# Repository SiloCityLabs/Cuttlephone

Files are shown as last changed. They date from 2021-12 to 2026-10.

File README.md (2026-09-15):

# Cuttlephone
Cuttlephone is phone case generator and gamepad system for 3D printing. This is the source code. [Get premade 3D models and print tutorials on the website](https://cuttlephone.com/)

phone case generator

3D printed phone case, in a 3D printed adapter for Razer Junglecat controllers

# Features
 - hard plastic (PLA+, ABS, PETG) or flexible (TPU)
 - phone case mode
 - universal phone clamp mode
 - Switch Joy-Con rails
 - Razer Junglecat rails
 
 # How to use phone case generator
 - install [OpenSCAD](https://openscad.org/downloads.html) version 2021.01 or greater
 - Download the code and its dependencies using the git command line: `git clone https://github.com/SiloCityLabs/Cuttlephone.git --recurse-submodules`
 - open the file "phone_case.scad" to use the GUI
 
 # Build scripts
 - in bash run `sh build.sh` to create all variants for all phones
 - GitHub Actions uploads those files to a [GitHub Release](https://github.com/SiloCityLabs/Cuttlephone/releases)

# How to run the docs blog locally

### With Docker:
 - `cd docs`
 - `docker compose up --build`
 - open http://127.0.0.1:4000/

### With Ruby on the host:
 - install Ruby 3.3 or newer, gem, and bundle
 - `cd docs`
 - `bundle install`
 - `sh run.sh`
 - watch the console for something like this: `Server address: http://127.0.0.1:4000/`

A GitHub token is optional. `jekyll-remote-theme` downloads the theme through the GitHub API, which is rate limited to 60 requests an hour without one. If you hit that limit:
- generate a token at https://github.com/settings/tokens/new with the scope *public_repo*
- copy `docs/.env.example` to `docs/.env`
- add token to `docs/.env`

# Build logs 

You can follow progress here:
 - [HackADay.io project log](https://hackaday.io/project/165606-cuttlephone-gamepad-phone-case)
 - [SiloCityLabs project blog / newsletter](https://silocitylabs.com/categories/projects/)
 - [SiloCityLabs Twitter](https://twitter.com/silocitylabs)

# Roadmap

...

Licensed under Creative Commons CC-BY-SA 4.0

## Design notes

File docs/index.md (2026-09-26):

---
title: Cuttlephone
nav_order: 1
---

# Cuttlephone: 3D printable phone cases 

Cuttlephone is the shape-shifting phone case. Download pre-made models or create your own with the OpenSCAD customizer.

## Features

### Hard plastic (PLA+, ABS) or flexibles (TPU)

Print rigid shells from common filament like PLA+ and PETG. Print flexible shells with integrated buttons using TPU.

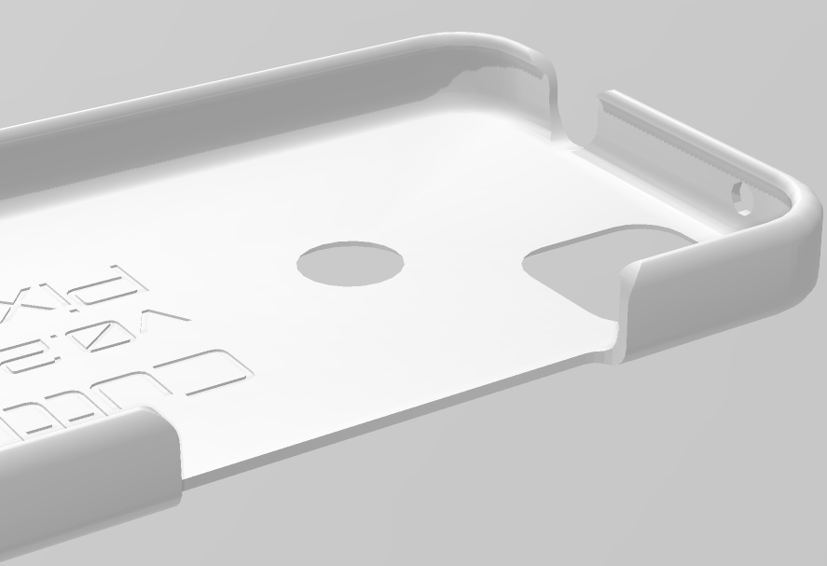
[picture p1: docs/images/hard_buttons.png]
Hard case with cut-out button holes
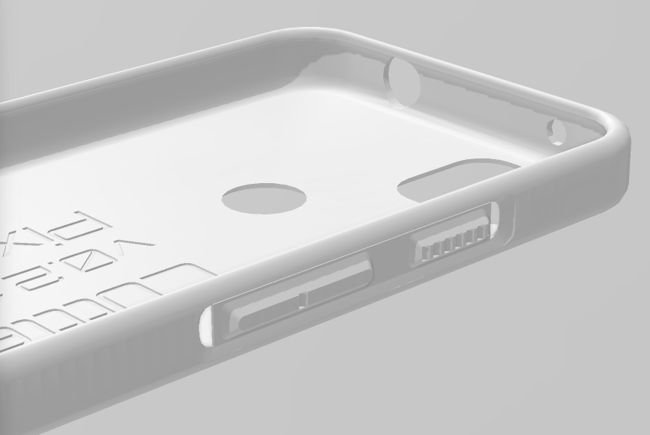
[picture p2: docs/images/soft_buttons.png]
Soft TPU phone case showing flexible push-through side buttons
  |  

### Phone case

Protective 3D printable phone cases sized for specific devices, with cutouts for camera, buttons, and ports, all tuned in the generator.

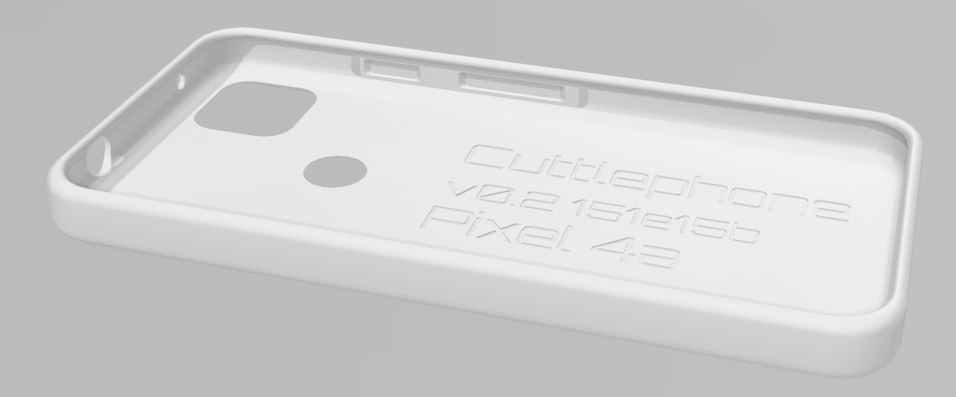
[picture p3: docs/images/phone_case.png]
3D render of a Cuttlephone protective phone case shell


### Switch Joy-Con rails

Slide-on rails for Switch Joy-Con controllers. Yes the locking notch and release button work!

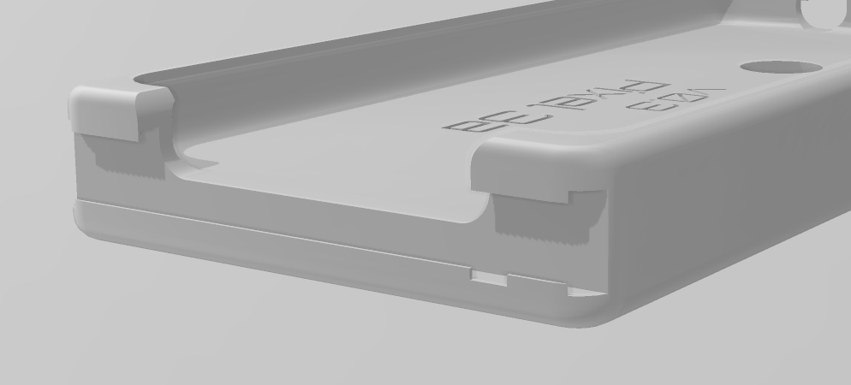
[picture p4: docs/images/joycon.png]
Phone case with Nintendo Switch Joy-Con slide rails on both sides


### Razer Junglecat rails

Slide-on rails for Razer Junglecat controllers.

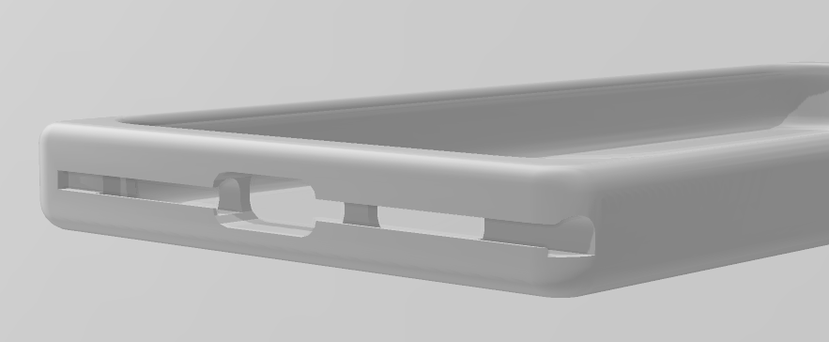
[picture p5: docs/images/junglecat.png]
Phone case with Razer Junglecat controller rails on both sides


### Universal controller adapter

A clamp-style adapter with rails for game controllers. Use one adapter across multiple devices.

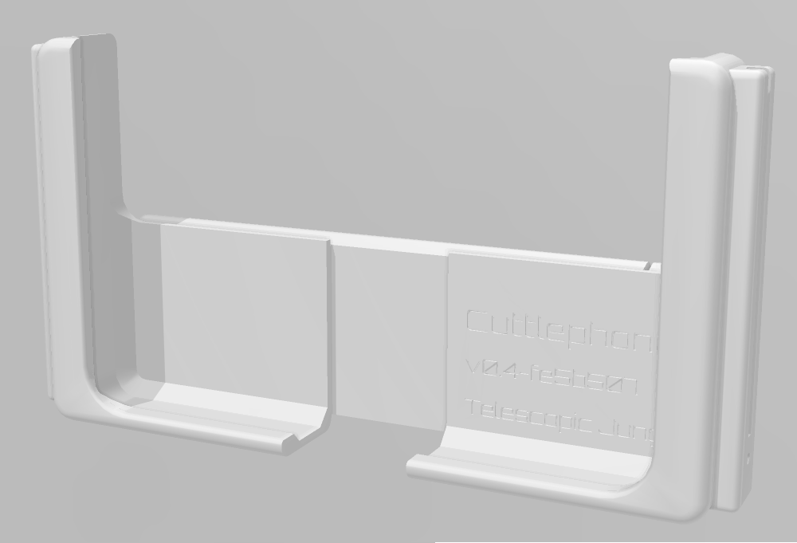
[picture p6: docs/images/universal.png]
Universal clamp phone adapter with controller rails


You can follow progress here:
 - [HackADay.io project log](https://hackaday.io/project/165606-cuttlephone-gamepad-phone-case)
 - [SiloCityLabs project blog / newsletter](https://silocitylabs.com/categories/projects/)
 - [SiloCityLabs Twitter](https://twitter.com/silocitylabs)

Licensed under Creative Commons CC-BY-SA 4.0

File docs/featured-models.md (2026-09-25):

---
layout: default
title: "Featured Models"
description: "User-tested Cuttlephone downloads: Pixel 4a Junglecat case, Joy-Con and Junglecat adapters, and Junglecat rail cutting tool."
permalink: /models/featured-models/
parent: 3D Models
nav_order: 1
---

# Featured Models

The best 3D models, tested by users. These models have been printed and used daily.

## Pixel 4a, with Junglecat rails

Cuttlephone version: v0.5

My daily phone case with Junglecat rails and our first mascot. Print with TPU. Use the [rail cutting tool](#junglecat-rail-cutting-tool) below to remove the support material.

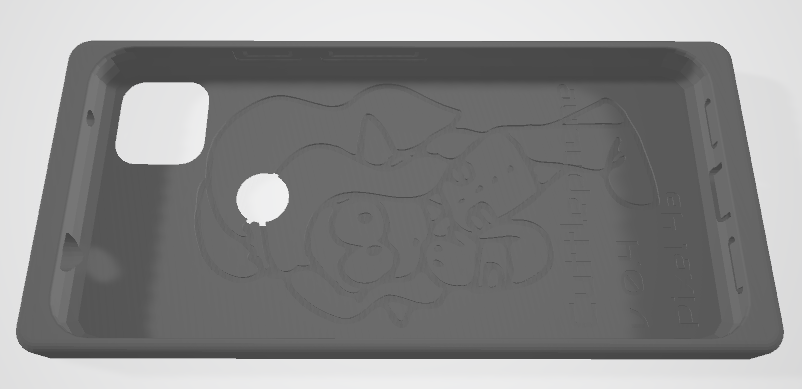
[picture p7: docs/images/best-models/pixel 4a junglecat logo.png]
Pixel 4a phone case with Junglecat rails (https://github.com/SiloCityLabs/Cuttlephone/releases/download/v0.5/Pixel_4a_junglecat_soft.3mf)


[3MF file](https://github.com/SiloCityLabs/Cuttlephone/releases/download/v0.5/Pixel_4a_junglecat_soft.3mf)

## Nintendo Switch Joy-Con controller adapters

Cuttlephone version: v0.5

Universal phone adapter with Joy-Con rails. Use a rubber band to clamp the two parts together. Comes in horizontal and vertical configurations. This model includes manual supports for the Joy-Con's rail locking notch, but you still need to support the other hanging parts. See the print guide.

[Horizontal:](https://github.com/SiloCityLabs/Cuttlephone/releases/download/v0.5/Telescopic_Joycon_joycon_hard.3mf)

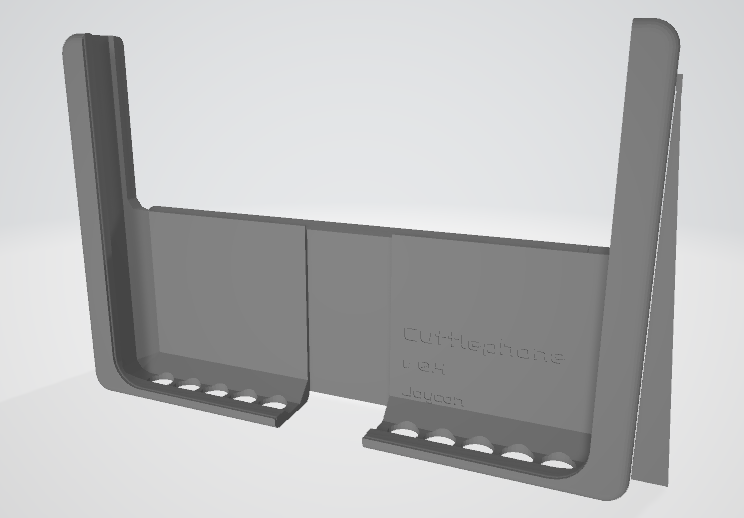
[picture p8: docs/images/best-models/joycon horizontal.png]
Joy-Con horizontal phone adapter (https://github.com/SiloCityLabs/Cuttlephone/releases/download/v0.5/Telescopic_Joycon_joycon_hard.3mf)


[Vertical:](https://github.com/SiloCityLabs/Cuttlephone/releases/download/v0.5/Telescopic_Joycon_Vertical_joycon_hard.3mf)

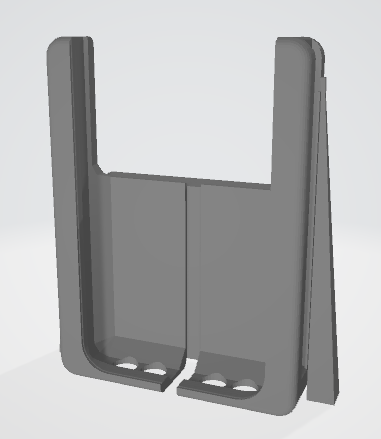
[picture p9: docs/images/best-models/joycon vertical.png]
Joy-Con vertical phone adapter (https://github.com/SiloCityLabs/Cuttlephone/releases/download/v0.5/Telescopic_Joycon_Vertical_joycon_hard.3mf)


## Razer Junglecat controller adapters

Universal phone adapter with Junglecat rails. Use a rubber band to clamp the two parts together.

[Horizontal:](https://github.com/SiloCityLabs/Cuttlephone/releases/download/v0.5/Telescopic_Junglecat_junglecat_hard.3mf)

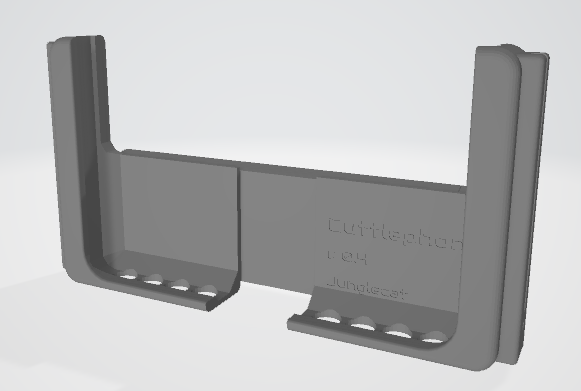
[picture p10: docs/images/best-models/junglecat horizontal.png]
Junglecat horizontal phone adapter (https://github.com/SiloCityLabs/Cuttlephone/releases/download/v0.5/Telescopic_Junglecat_junglecat_hard.3mf)


[Vertical:](https://github.com/SiloCityLabs/Cuttlephone/releases/download/v0.5/Telescopic_Junglecat_Vertical_junglecat_hard.3mf)

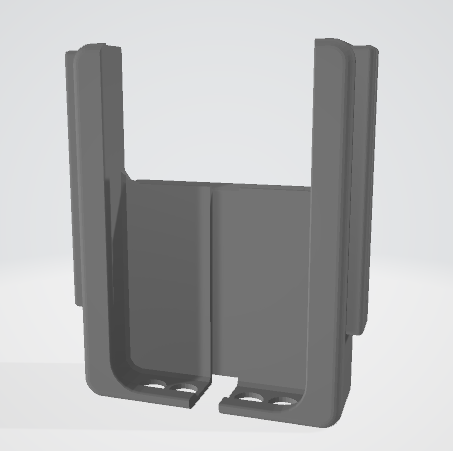
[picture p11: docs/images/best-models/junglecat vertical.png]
Junglecat vertical phone adapter (https://github.com/SiloCityLabs/Cuttlephone/releases/download/v0.5/Telescopic_Junglecat_Vertical_junglecat_hard.3mf)


## Junglecat rail cutting tool

A tool to help cut the support material from the Junglecat rails. For phone cases, printed flat, with the manual supports.

[Rail cut tool:](https://github.com/SiloCityLabs/Cuttlephone/releases/download/v0.5/Junglecat_rail_cut_tool.3mf)

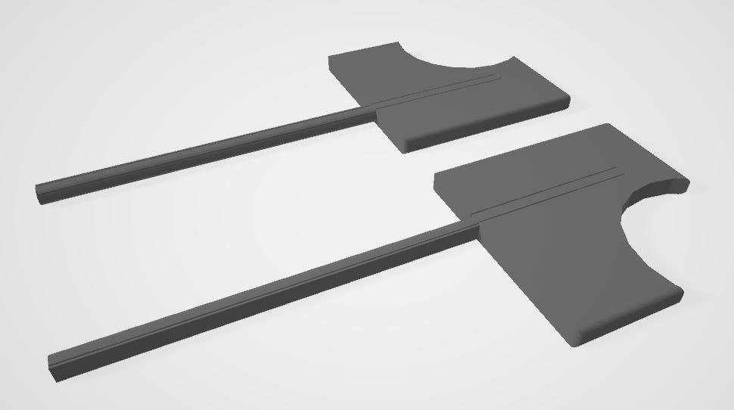
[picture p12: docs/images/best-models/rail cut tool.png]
Rail cutting tool (https://github.com/SiloCityLabs/Cuttlephone/releases/download/v0.5/Junglecat_rail_cut_tool.3mf)


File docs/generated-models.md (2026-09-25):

---
layout: default
title: "Generated Models"
description: "Download every Cuttlephone phone case variant in hard or soft materials, with optional Joy-Con or Junglecat rails."
permalink: /models/generated-models/
parent: 3D Models
nav_order: 2
---

# Generated models
Below you'll find models of every available phone case with every available variation. I generate a new batch with each significant revision of the program. 

Models are from the [latest release]({{ site.github.repository_url }}/releases/latest).

{% for material in site.data.case_materials %} For {{ material.material }} cases, print with {{material.example}}. {% endfor %} Read the [3D printing guide](/guides/print-guide/) for more tips.

<style>
  a.model-link {
    display: inline-block;
    margin: 0.2em 0.4em 0.2em 0;
  }
</style>

<!-- loop through phone_case.json -->
{% for model in site.data.phone_case.parameterSets %}
{% if model[1].in_development != "true" %}
<!-- hide models that don't have build output -->
{% assign any_built = "" %}
{% for type in site.data.model_types %}
{% if type.build_key %}
{% assign build_flag = model[1][type.build_key] %}
{% if build_flag == "true" %}{% assign any_built = "yes" %}{% endif %}
{% endif %}
{% endfor %}
{% if any_built == "yes" %}
## {{ model[0] }}

<table>
<thead>
<tr>
<th>Type</th>
{% for material in site.data.case_materials %}
{% assign mat_built = "" %}
{% if material.material == "hard" and model[1].build_hard == "true" %}{% assign mat_built = "yes" %}{% endif %}
{% if material.material == "soft" and model[1].build_soft == "true" %}{% assign mat_built = "yes" %}{% endif %}
<!-- muted text if no build output -->
<th{% unless mat_built == "yes" %} style="opacity:0.45;font-weight:500"{% endunless %}>{{ material.material | capitalize }}</th>
{% endfor %}
</tr>
</thead>
<tbody>
{% for type in site.data.model_types %}
{% if type.build_key %}
{% assign build_flag = model[1][type.build_key] %}
{% if build_flag == "true" %}
{% include_relative premade-models-link.md %}
{% endif %}
{% endif %}
{% endfor %}
</tbody>
</table>
{% endif %}
{% endif %}
{% endfor %}

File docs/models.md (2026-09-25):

---
layout: default
title: "3D Models"
description: "Download featured and generated Cuttlephone 3D printable phone cases, Joy-Con adapters, and Junglecat adapters. Preview pre-built models in the browser."
permalink: /models/
has_children: true
has_toc: false
heading_anchors: false
---

# 3D Models

## [Featured Models](/models/featured-models/)

The best phone cases and controller adapters, as tested by users.

## [Generated models](/models/generated-models/)

All 3D models - all phone models with each variation of material and controller

## [3D Preview](/models/preview/)

Rotate and zoom a release model in the browser

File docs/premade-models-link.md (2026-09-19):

<tr>
<td>{{ type.model_type }}</td>
{%- for material in site.data.case_materials -%}
<td>
<!-- loop through materials -->
<!-- Liquid has no real booleans; assign false becomes the truthy string "false" -->
{%- assign can_build = "" -%}
{%- if material.material == "hard" and model[1].build_hard == "true" -%}{%- assign can_build = "yes" -%}{%- endif -%}
{%- if material.material == "soft" and model[1].build_soft == "true" -%}{%- assign can_build = "yes" -%}{%- endif -%}
{%- if can_build == "yes" -%}
{%- capture filename %}{{ model[0] }} {{ type.model_type }} {{ material.material }}.3mf{% endcapture -%}
<!-- github-safe file names -->
{%- assign filename = filename | strip | replace: " ", "_" | replace: "+", "plus" -%}
<a class="model-link" href="{{ site.release_download_url }}{{ filename }}">Download 3MF</a>
<br>
<a class="model-link" href="{{ '/models/preview/' | relative_url }}?model={{ filename | url_encode }}{% if model[1].rotate_upright == "true" %}&rotate_upright=true{% endif %}">Preview</a>
{%- endif -%}
</td>
{%- endfor -%}
</tr>

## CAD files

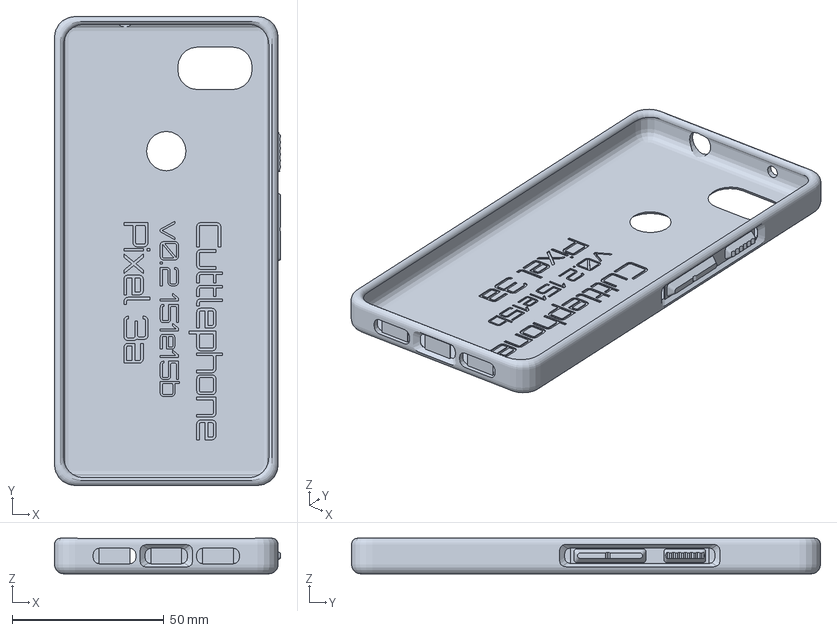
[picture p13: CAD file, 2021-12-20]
docs/premade_models/Pixel 3a phone case soft.3mf
74.6 x 154.7 x 11.8 mm

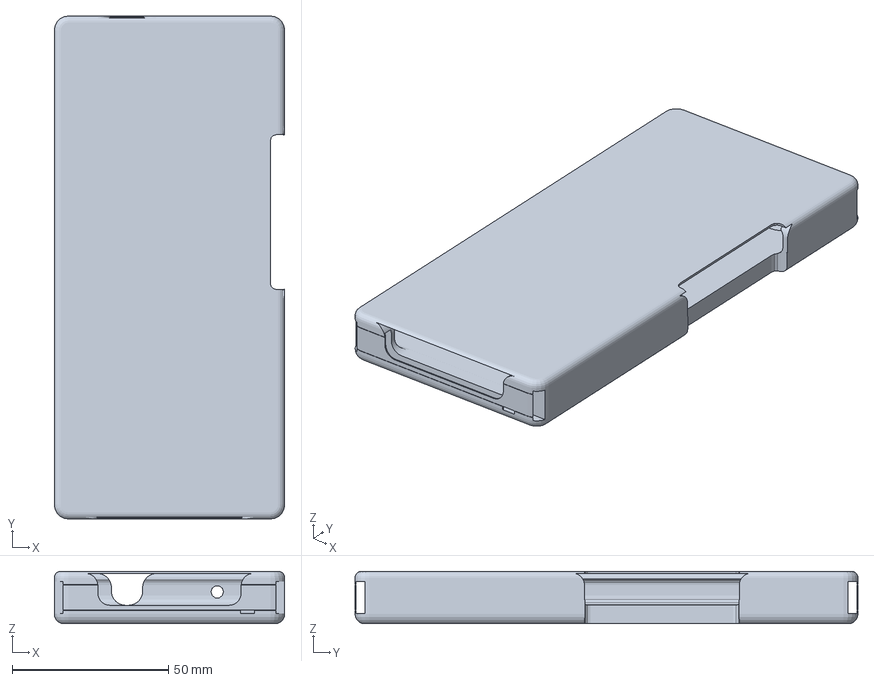
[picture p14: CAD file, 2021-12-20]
docs/premade_models/Pixel 3a joycon hard.3mf
73.8 x 161.1 x 16.8 mm

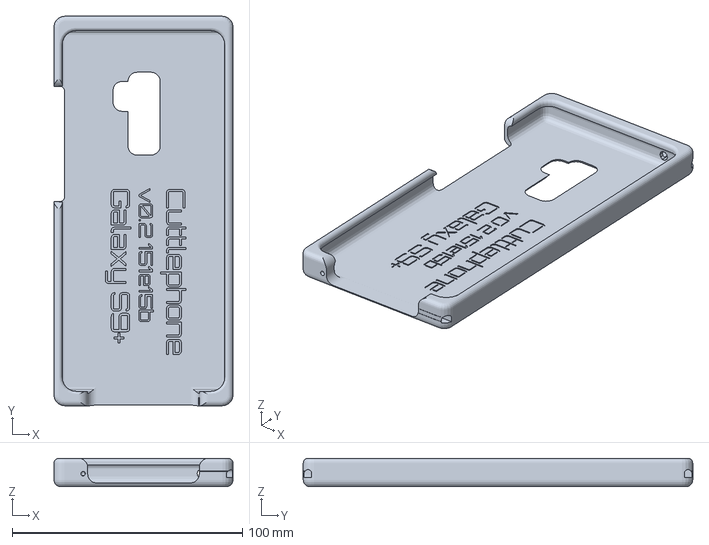
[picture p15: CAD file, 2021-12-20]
docs/premade_models/Galaxy S9+ junglecat hard.3mf
77.7 x 169.1 x 12.3 mm

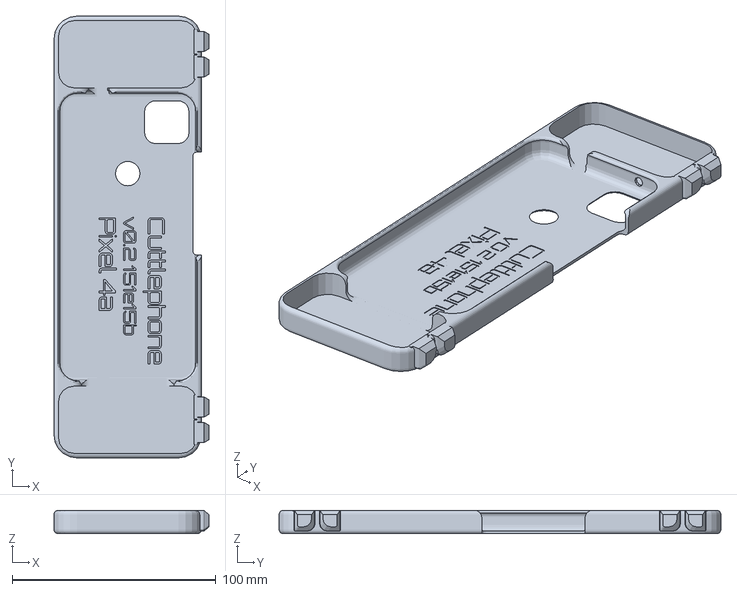
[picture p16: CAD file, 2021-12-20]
docs/premade_models/Pixel 4a gamepad hard.3mf
76.0 x 216.6 x 11.4 mm

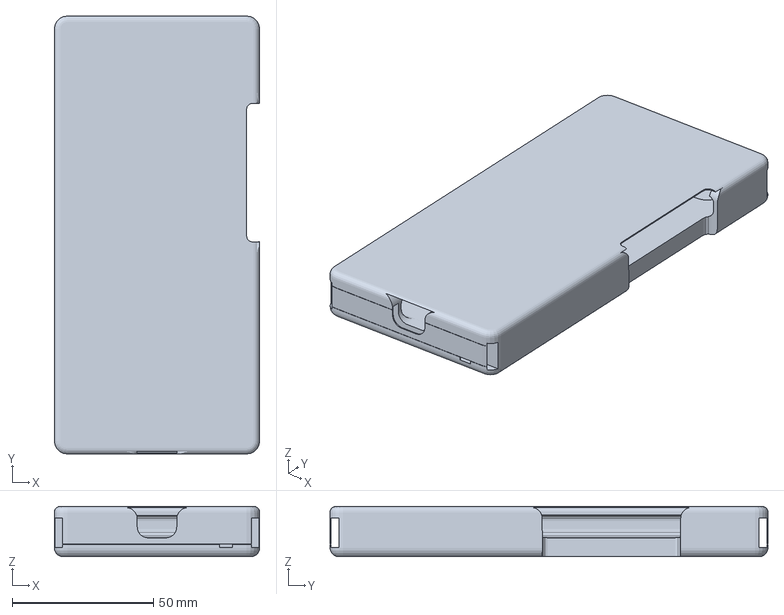
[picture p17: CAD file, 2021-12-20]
docs/premade_models/Pixel 3 joycon hard.3mf
72.7 x 155.1 x 17.8 mm

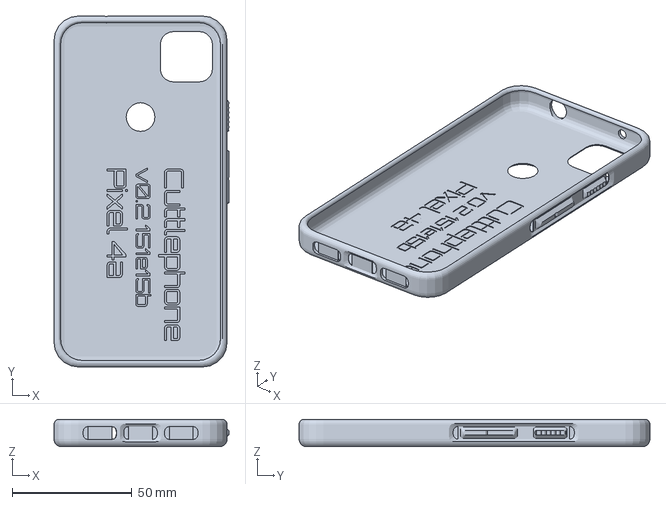
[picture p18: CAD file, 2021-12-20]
docs/premade_models/Pixel 4a phone case soft.3mf
73.1 x 146.6 x 11.4 mm

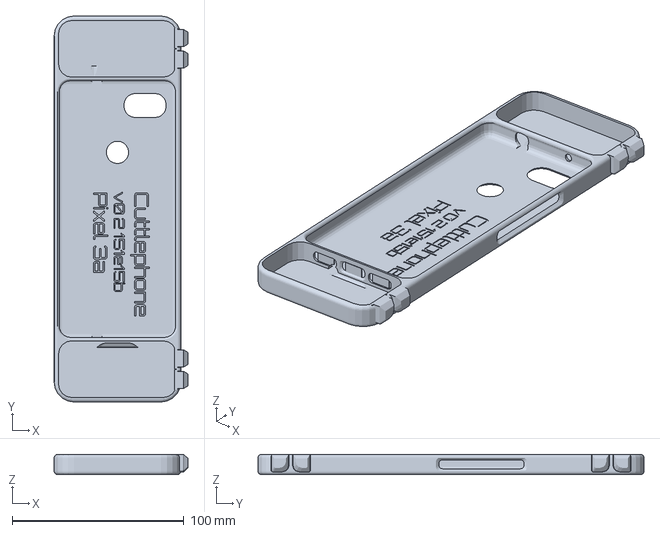
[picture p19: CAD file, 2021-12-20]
docs/premade_models/Pixel 3a gamepad soft.3mf
77.9 x 224.7 x 11.8 mm

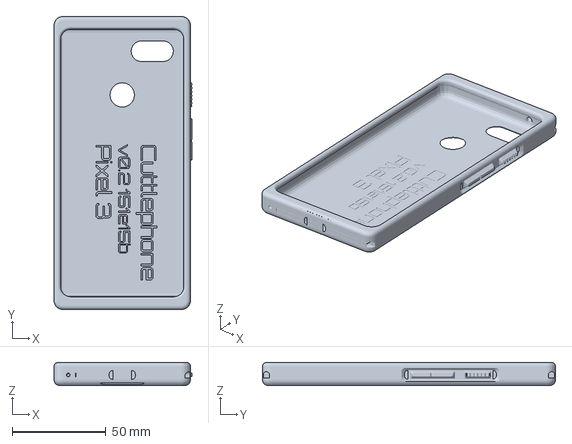
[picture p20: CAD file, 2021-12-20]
docs/premade_models/Pixel 3 junglecat soft.3mf
73.5 x 156.1 x 12.3 mm

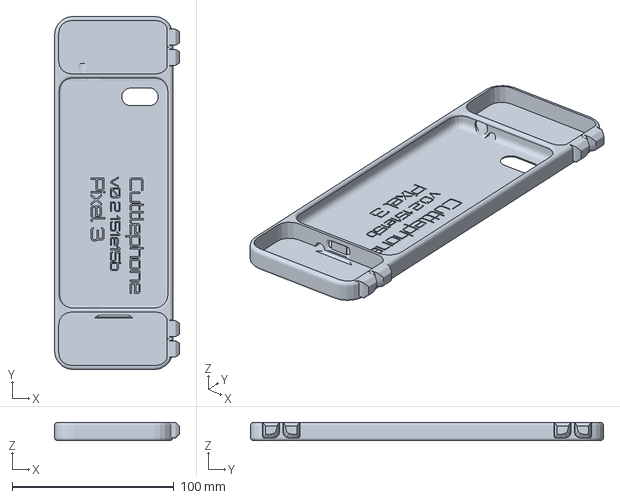
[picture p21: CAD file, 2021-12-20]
docs/premade_models/Pixel 3 XL gamepad soft.3mf
77.4 x 218.7 x 11.3 mm

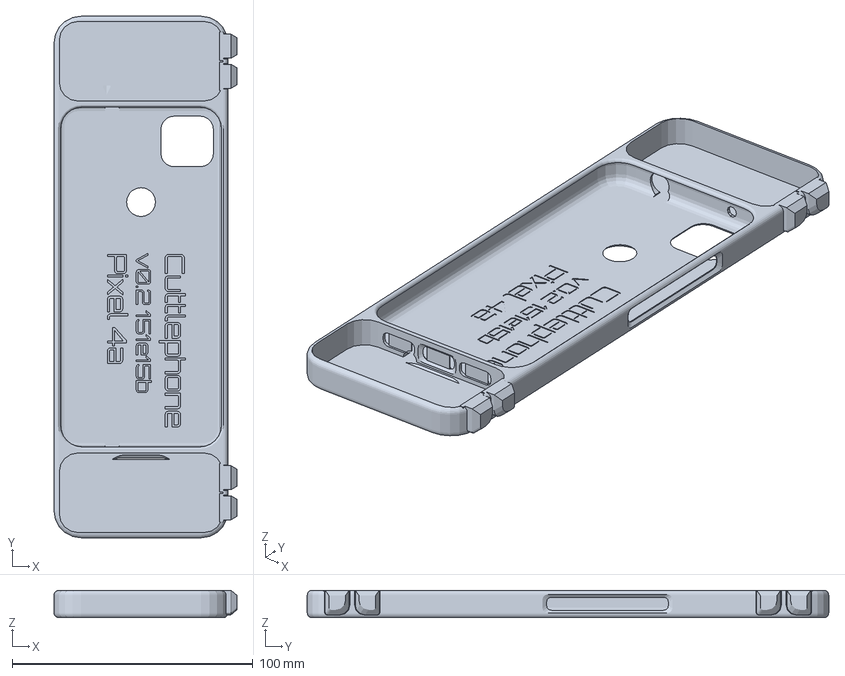
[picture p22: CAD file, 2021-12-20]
docs/premade_models/Pixel 4a gamepad soft.3mf
76.0 x 216.6 x 11.4 mm

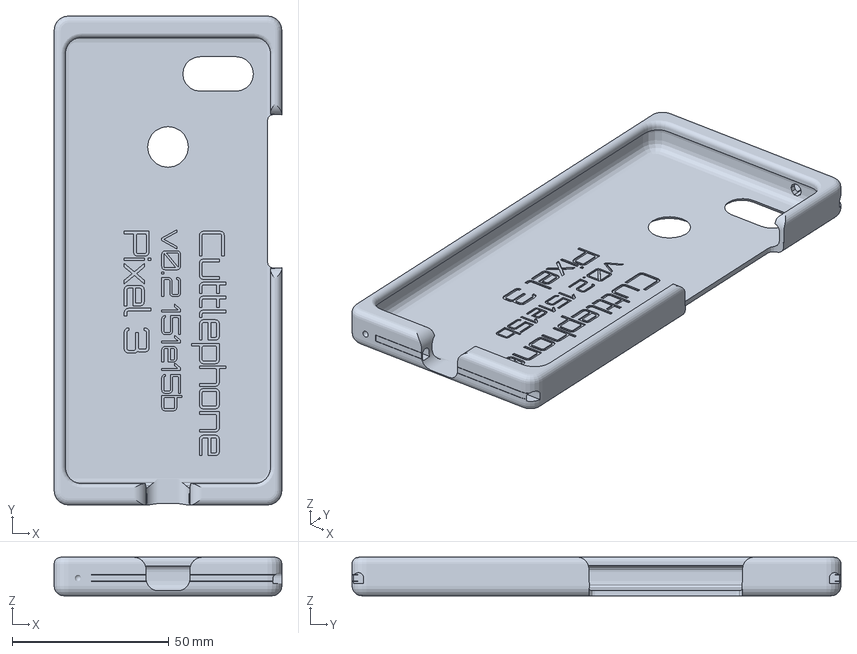
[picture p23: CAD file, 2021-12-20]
docs/premade_models/Pixel 3 junglecat hard.3mf
72.7 x 156.1 x 12.3 mm

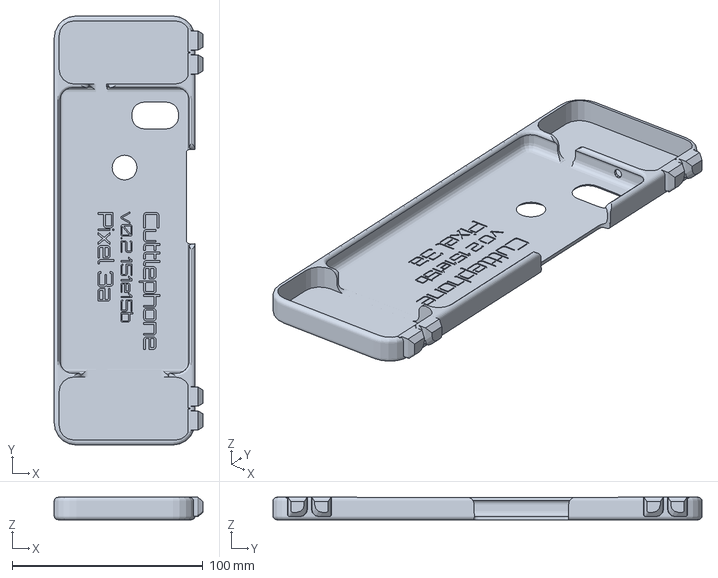
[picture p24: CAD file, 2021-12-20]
docs/premade_models/Pixel 3a gamepad hard.3mf
77.9 x 224.7 x 11.8 mm

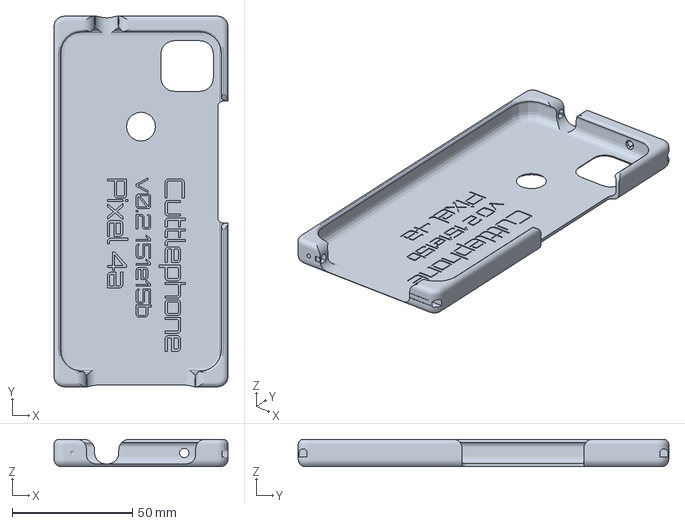
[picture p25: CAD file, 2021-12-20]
docs/premade_models/Pixel 4a junglecat hard.3mf
72.3 x 154.0 x 11.4 mm

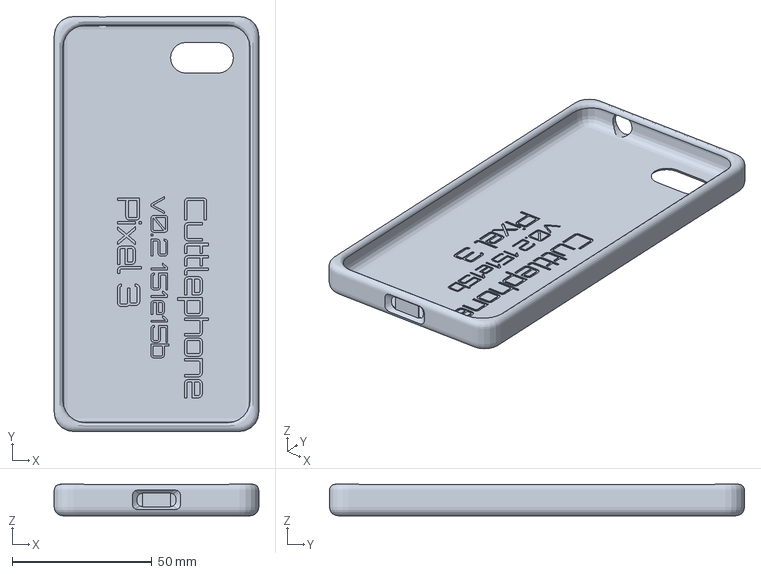
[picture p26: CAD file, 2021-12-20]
docs/premade_models/Pixel 3 XL phone case soft.3mf
73.3 x 148.7 x 11.3 mm

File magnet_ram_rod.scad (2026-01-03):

include <libraries/BOSL2_submodule/std.scad>

$fn=35;

magnet_width = 7.1; // [ 0.1 : 0.1 : 10  ]
magnet_depth = 1.7; // [ 0.1 : 0.1 : 10  ]
taper_width = 0.1; // [ 0 : 0.1 : 1.5  ]
//cup_depth = 1.0;

holder_length = 6.9; // [ 1 : 1 : 12 ]
hex_length=12; // [ 1 : 1 : 20 ]

// size of the chuck in mm. 1/4"==6.35mm
hex_diam=6.35; // 1/4 inch from flat to flat
slot_width=6.7;

smidge=0.01;

// m3 screw == 2.6mm hole
screw_hole_diam = 2.6; 

difference() {
    union() {
        // hex shank
        rotate([180,0,0])
        linear_extrude(height=hex_length) {
            hexagon(
                id=hex_diam
            );
        }
        
        // magnet holder
        cyl(
            d=magnet_width*1.3, 
            h=holder_length,
            anchor=BOTTOM
        );
        
        // taper down so we don't need supports
        cyl(
            d1=hex_diam/2, 
            d2=magnet_width*1.3, 
            h=holder_length,
            anchor=TOP
        );
    }
    
    // cup cutout to hold magnet
    translate([0,0,holder_length+smidge])
    cyl(
        d1=magnet_width,
        d2=magnet_width+taper_width,
        h=magnet_depth,
        anchor=TOP
    );
    
    // shave sides to fit in the joycon2 slot
    translate([-slot_width/2,0,0])
    cuboid([50,50,50], anchor=BOTTOM+RIGHT);
    
    translate([slot_width/2,0,0])
    cuboid([50,50,50], anchor=BOTTOM+LEFT);
    
    
    // screw hole for magnetic screwdriver shaft
    translate([0,0,-hex_length-smidge])
    cyl(d=screw_hole_diam, h=hex_length, anchor=BOTTOM);
    
}

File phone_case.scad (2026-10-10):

/* Phone case generator.
 * Supports phone case, Joycon rails, Junglecat rails, and Cuttlephone gamepad
 * Designed for FDM 3D printing with PLA+ or TPU, 0.4mm nozzle, 0.2mm layer height.
 * Author: Maave
 */

use <fonts/orbitron/orbitron-light.otf>
use <fonts/Baloo_2/Baloo2-VariableFont_wght.ttf>
use <fonts/Audiowide/Audiowide-Regular.ttf>

// The Belfry OpenScad Library, v2
// These have to be imported using an "include" statement because several variables for things like anchors are defined in here.
include <libraries/BOSL2_submodule/std.scad>
include <libraries/BOSL2_submodule/geometry.scad>
include <libraries/BOSL2_submodule/rounding.scad>
include <libraries/BOSL2_submodule/shapes3d.scad>

/*  measurements from the phone
 *  all values are in mm
 *  Customizer UI precision (0.1, 0.01) is based on the comments
 */

/* [shell] */

case_material = "hard"; // [hard, soft]
case_type = "phone case"; // [phone case, gamepad, joycon, joycon2, junglecat]

case_thickness = 1.6; // [0 : 0.1 : 4]
// make the back surface thicker (for sturdier universal adapters)
back_thickness_bonus = 0; // [-1 : 0.1 : 2]
//if the screen is curved and the case cutaway, you might want some extra grip
shell_side_stickout = 0; // 0.1
// Thin the shell lips around the screen bezels, keeping full case thickness at the top and bottom
shell_enable_angled_screen_bezels = false;
// Thickest the lip should be on the outer edges (in practice - a little under that due to curves used)
shell_screen_max_lip_outer = 2; // 0.1
// Thinnest the lip should be on the inner edges
shell_screen_min_lip_inner = 1; // 0.1

lanyard_loop = false;
lanyard_reinforcement = false;

/* [emboss] */
phone_model = "Sample case";
emboss_size = "large"; // [logo, large, medium, small, very_small, none]
// Text rotation on the back wall. Use -90 for rotate_upright prints.
emboss_rotate = 90; // [-90, 0, 90]
//Check available fonts in the menu Help > Font List. Simple sans-serif fonts will print better.
emboss_font = "Audiowide";
font_size = 7.1; // 0.1
small_font_size = 6.1; // 0.1
emboss_logo = "logos/dude.svg";
logo_x = 0.0; // 0.1
logo_y = 0.0; // 0.1
// Which face to cut for text/logo
emboss_face = "inside"; // [inside:inside (phone) face, outside:outside face]

/* [magsafe] */
// Magnetic Power Profile / MagSafe
magsafe_ring = false;
// Which face to cut for MagSafe ring recess
magsafe_face = "inside"; // [inside:inside (phone) face, outside:outside face]
// cut the magsafe emboss deeper
deep_emboss = false;
// leave 2 layer of material
deepest_emboss = 0.3;
// Qi wireless charger location. If you don't have wireless charging then magsafe can go anywhere
magsafe_offset_from_center = -7.5; // [ -15 : 0.1 : 5 ]  // TODO: measuring "offset from center" sucks, find a hard reference point
// metal thickness in Z direction
magsafe_thickness = 0.75; // [0.30 : 0.05 : 1.60]
// spec: 46.00
magsafe_ring_inner_diam = 45.4; // [42 : 0.1 : 47]
// spec: 54.10
magsafe_ring_outer_diam = 55.8; // [48 : 0.1 : 59]
// alignment magnet for MagSafe. Not needed for steel ring
magsafe_alignment_magnet = true;
// spec: 6.00
magsafe_alignment_w = 6.10; // [ 5 : 0.01 : 8 ]
// spec: 19.31
magsafe_alignment_l = 19.31; // [ 19 : 0.01 : 21 ]
/* [Hidden] */
alignment_offset_center_to_center = -40.835; // no touch



/* [3D print] */

//this will support the rail and some overhangs during a horizontal print, and support the Joycon lock notch on a vertical print
manual_supports = true;
support_thickness = 0.4; // [0.1:1 : 0.01]
//This will make a gap in between the supports and the object. Set this to approx your layer height. 
support_airgap = 0.20;  // [0.0:0.4 : 0.01]
//for soft case cutouts, don't support on the curved part 
manual_support_retract = 2; // [0:1:2]
rotate_upright = false;
//the telescoping back can warp, hold it onto the bed
telescopic_back_support = false;
// I didn't calculate this, tune it yourself
brick_z = 1.0; // 0.1
brick_x = 5;
brick_y = 0.5;
brick_bottom_x = brick_x*2;
brick_bottom_y = brick_y*3;
//joycon 2 magnet
magnet_width = 7.05; // measured 6.97
magnet_depth = 3.45; // measured 2.97
round_magnet=true;
double_magnet=true;
// for bar magnets
magnet_length = 15.2; // measured 14.89

//Chop the case in half for a test print to see how it fits. To check body_radius, use "top_half_pla".
test_cut = "none"; //[none, corners, right_edge, right_buttons, left_edge, bottom_edge, top_edge, left_button, top_half_pla, telescopic]

//A plastic guide to help you cut the support out of the Joycon or Junglecat rails
rail_cut_tools = false;

render_quality="quick"; // [quick, nice, export]

/* [debug view] */
show_phone_body=false;
transparent_body=false;
transparent_shell=false;
show_cuts=false;
transparent_cuts=false;
show_shell_centerline=false;

/* [body] */

body_length = 140.0; // 0.1
body_width = 50.0; // 0.1
body_thickness = 8.1; // 0.1
//rounding of the corners when viewed screen-up.
body_radius = 5.25; // 0.01
body_radius_top = 2.1; // 0.01
body_radius_bottom = 3.1; // 0.01
//replaces the round radius with a 45-degree cut
body_chamfer = false;
body_chamfer_angle_top = 45; // [1:1:89]
body_chamfer_angle_bottom = 45;// [1:1:89]
//for phones with different rounding on the sides, like Galaxy S9
body_bottom_side_radius = 0.1; // 0.01
//decrease for shallow shallow curves like the S9
body_bottom_side_angle = 90; // 0.1

/* [screen] */

screen_radius = 8.01; // 0.01
screen_lip_length = 3.1; // 0.1
screen_length = body_length - screen_lip_length;
screen_lip_width = 3.1; // 0.1
screen_width = body_width - screen_lip_width;
//left/right curved screen radius
screen_curve_radius = 0.1; // 0.1
//decrease for shallow shallow curves like the S9
screen_curve_angle = 90; // 0.1
//cuts away the side of the case for curved screens
screen_undercut = 0.1; //default is 0.01 because of Openscad precision bug
// how much the case sticks up, so the screen is recessed. 0=flush. 0.1-0.4 for screen protectors.
screen_lip = 0.1; // [0 : 0.1 : 2]
//NOT WORKING: if the corners are sharp, add some "ramp" to the sides
extra_sides = false;
//use these if one of the corners is particularly loose and you've already tuned the body tight
screen_extra_top_left = 0; // 0.1
screen_extra_top_right = 0; // 0.1
screen_extra_bottom_left = 0; // 0.1
screen_extra_bottom_right = 0; // 0.1

/* [charge, bottom speakers] */
charge_on_bottom = true;
// up / down
charge_z_offset = 0; // [-5 : 0.1 : 5]
// left / right
charge_x_offset = 0; // [-40 : 0.1 : 40]
charge_cutout_bevel_angle_y = 10;
charge_cutout_bevel_angle_z = 10;

// USB Type C spec: 12.35 x 6.5 for the overmold portion of a plug
usb_cut_width = 13.0;
// height for soft cases only
usb_cut_height = 7.0;
//usb_cut_rounding = 1.0;

// one wide opening instead of separate USB and speaker holes. Hard cases only.
combine_usb_and_speakers = true;

bottom_speakers_right = false;
bottom_speakers_left = false;
// distance from edge of phone to speaker cutout
speaker_left_from_edge = 12.9; // 0.1
speaker_right_from_edge = 12.9; // 0.1
bottom_speaker_vertical_offset_from_center = 0.0; // 0.1
bottom_speaker_width = 10.5; // 0.1
bottom_speaker_height = 1.2; // 0.1

/* [headphone, mic] */
mic_on_top = false;
mic_on_bottom = false;
top_mic_from_right_edge = 14.1; // 0.1
bottom_mic_from_right_edge = 14.1; // 0.1
top_mic_offset_up = 0.1; // 0.1
bottom_mic_offset_up = 0.1; // 0.1
headphone_from_left_edge = 14.1; // 0.1
headphone_on_top = false;
headphone_on_bottom = false;
// vertical offset
headphone_z_offset = 0; // [-3 : 0.1 : 3]

/* [buttons - on the phone's body] */
right_power_button = false;
right_power_from_top = 31.1; // 0.1
right_power_length = 10.1; // 0.1
right_volume_buttons = false;
right_volume_from_top = 50.1; // 0.1
right_volume_length = 20.1; // 0.1
left_power_button = false;
left_power_from_top = 30.1; // 0.1
left_power_length = 10.1; // 0.1
left_volume_from_top = 50.1; // 0.1
left_volume_buttons = false;
left_volume_length = 20.1; // 0.1

//moves the buttons toward the screen (positive) or toward the back panel (negative). Buttons are centered by default
buttons_vertical_fudge = 0.1; // 0.1

// how much to the buttons protrude from the device body's edge in the X or Y axis
button_body_protrusion = 0.5; // 0.01

// how thick are the buttons in the Z axis?
button_case_thickness = 2; // 0.1

/* [buttons - on the case] */
// how much should the buttons protrude out of the case in the X or Y axis
button_shell_protrusion = 0.8; // 0.1

// Button and wall position in the shell, 0 being right on the phone, 100 on the outer edge of the case. (Values further away from center may or may not work well depending on the case thickness and shape of the device.)
button_wall_offset_percentage = 50; // [10.0:0.1:90.0]
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

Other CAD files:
docs/premade_models/Pixel 3a junglecat hard.3mf
docs/premade_models/Pixel 3 gamepad soft.3mf
docs/premade_models/Galaxy S9+ gamepad hard.3mf
docs/premade_models/Pixel 3 XL junglecat soft.3mf
docs/premade_models/Galaxy S9+ gamepad soft.3mf
docs/premade_models/Galaxy S9+ joycon hard.3mf
docs/premade_models/Galaxy S9+ joycon soft.3mf
docs/premade_models/Galaxy S9+ junglecat soft.3mf
docs/premade_models/Galaxy S9+ phone case hard.3mf
docs/premade_models/Galaxy S9+ phone case soft.3mf
docs/premade_models/Pixel 3 XL gamepad hard.3mf
docs/premade_models/Pixel 3 XL joycon hard.3mf
docs/premade_models/Pixel 3 XL joycon soft.3mf
docs/premade_models/Pixel 3 XL junglecat hard.3mf
docs/premade_models/Pixel 3 XL phone case hard.3mf
docs/premade_models/Pixel 3 gamepad hard.3mf
docs/premade_models/Pixel 3 joycon soft.3mf
docs/premade_models/Pixel 3 phone case hard.3mf
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

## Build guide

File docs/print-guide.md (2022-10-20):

---
layout: default
title: "Print Guide"
permalink: /print-guide/
---

# Slicer settings and tuning

Tune your printer and slicer. Epsecially tune the linear advance setting to prevent blobbing. 3-5 perimeters. About 0.15mm layer height.

If you can print a pretty Benchy then you can print this phone case. My overhangs here could've been a little better but this is more than good enough:

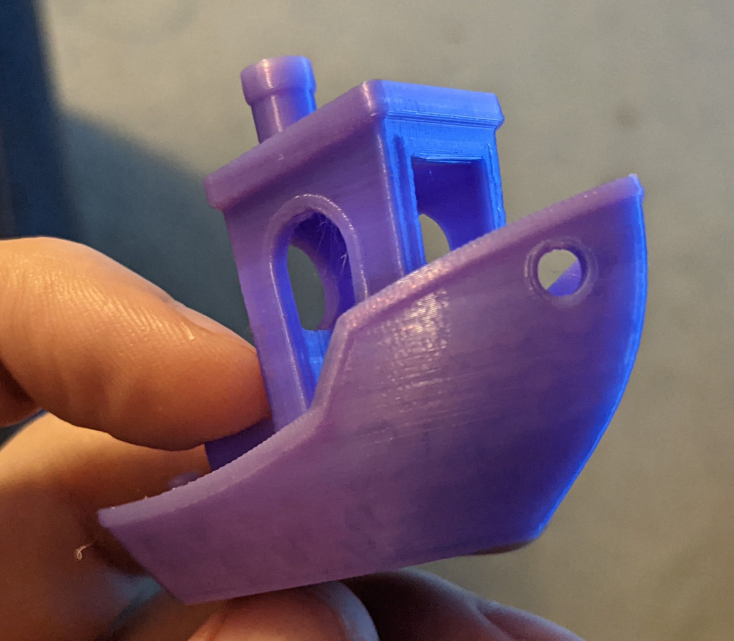
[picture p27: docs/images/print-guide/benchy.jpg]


Variable extrusion width in the slicer will make the rails much better. Cura 5.0 and PrusaSlicer 2.5 both have this feature. Some companies reskin Cura as their own slicer - use the latest version of regular Cura instead.

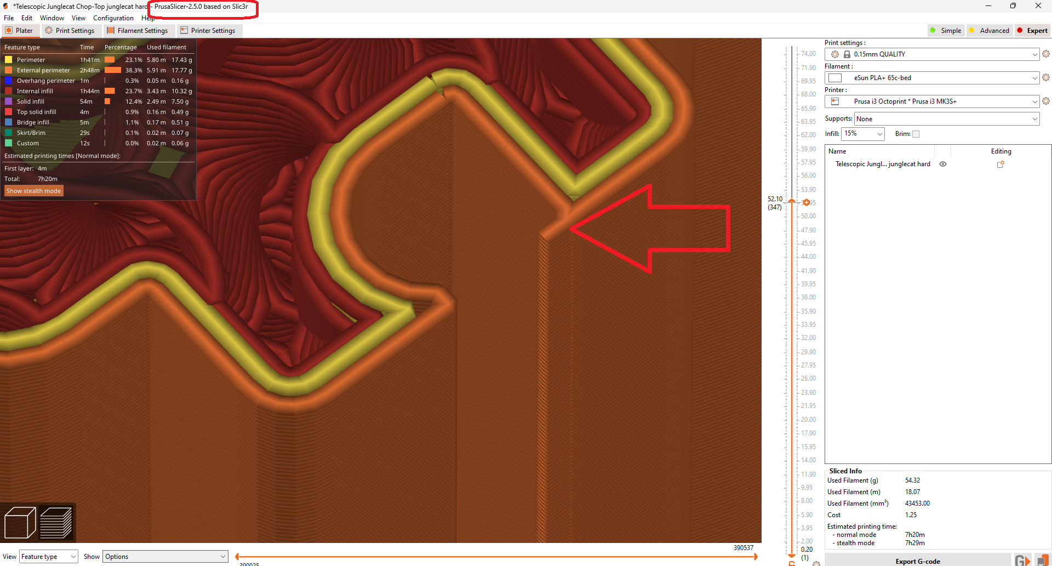
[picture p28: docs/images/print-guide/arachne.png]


# Materials

The hard cases can be made using PLA+, PETG, or ABS/ASA. Ductile materials. Plain PLA is too brittle and it will crack. Any brand of PLA+ (PLA Pro) will work, from Polymaker to eSun.

The soft cases can be made from TPU with a hardness of 90A or more. Overture High Speed TPU is the only one I've used and it's the perfect stiffness for a phone case. Supposedly this material works in bowden printers like the Ender 3.

# Splitting clamps

Import the model into your slicer. Split the model and separate the 2 halves. Enable supports on the build plate. Don't support the inside of the sliding slot.

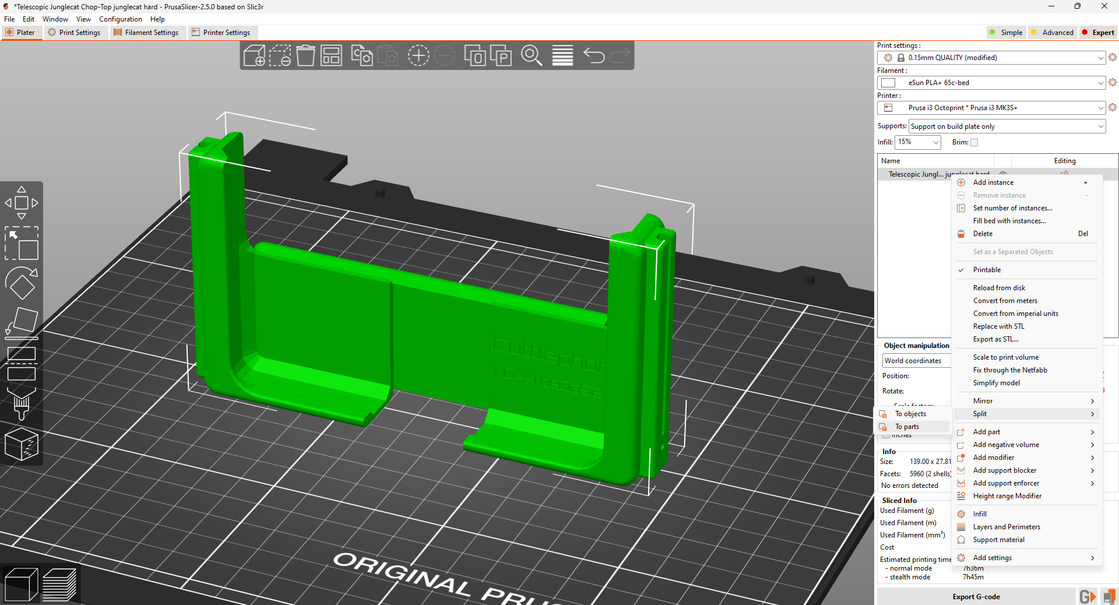
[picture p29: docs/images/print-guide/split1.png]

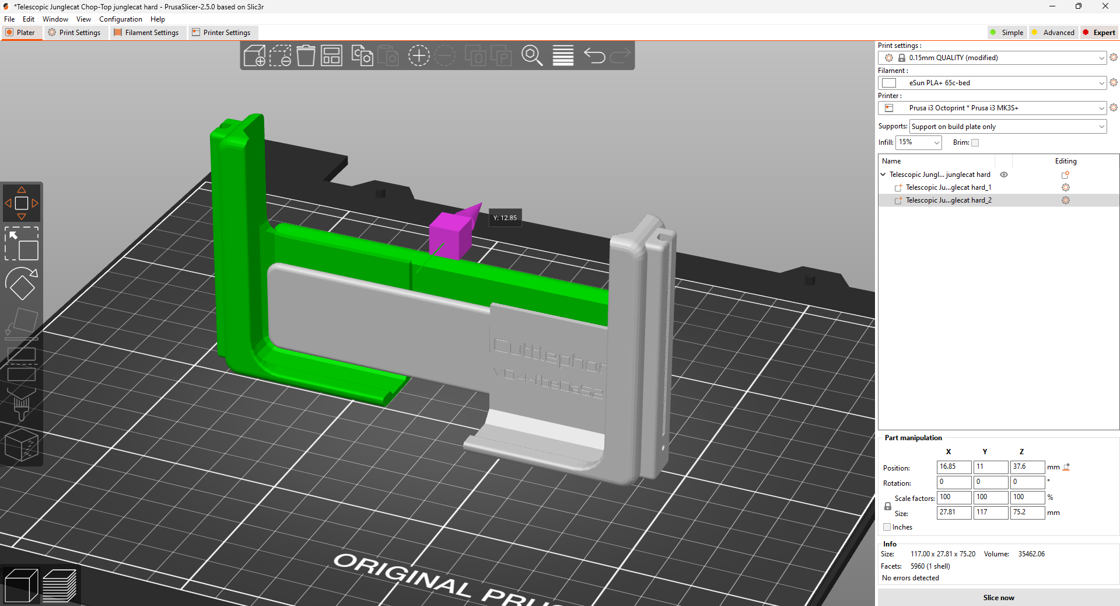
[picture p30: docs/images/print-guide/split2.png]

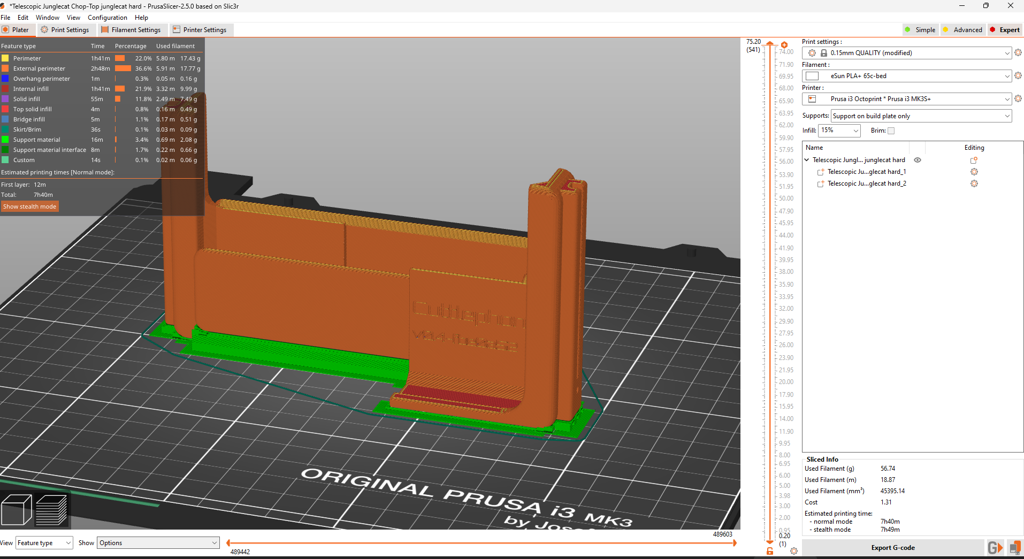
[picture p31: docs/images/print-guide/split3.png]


# Manual vertical supports
The Joy-Con rails have manual supports. Move them along with the clamp. 

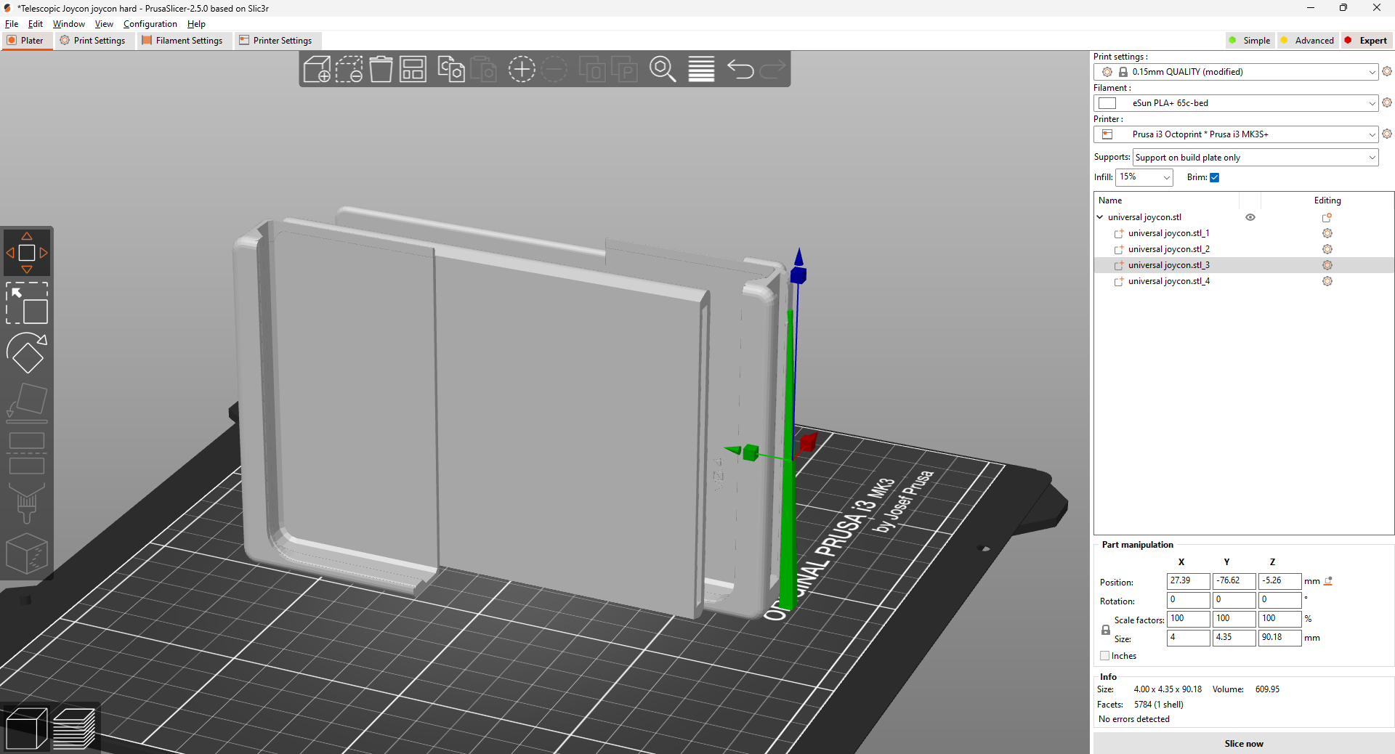
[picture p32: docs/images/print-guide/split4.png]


# Manual horizontal supports 

Manual supports are used for some overhangs to prevent sagging. Cut away with a craft knife or sharp box cutter.

Phone overhang support
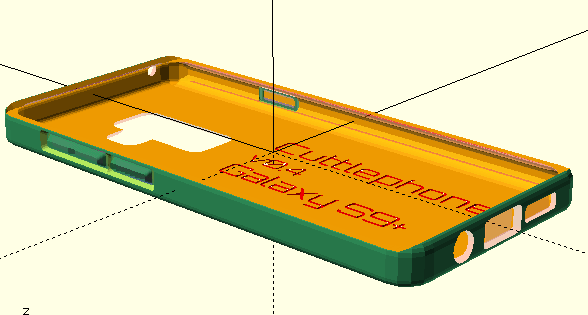
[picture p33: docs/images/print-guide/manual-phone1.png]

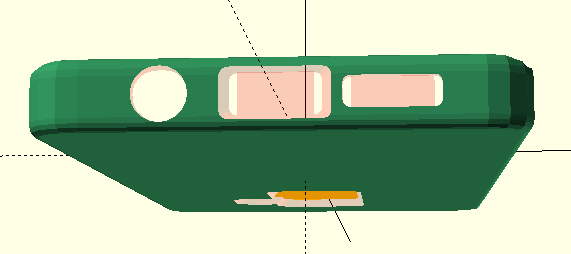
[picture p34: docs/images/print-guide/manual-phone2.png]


Junglecat rail support
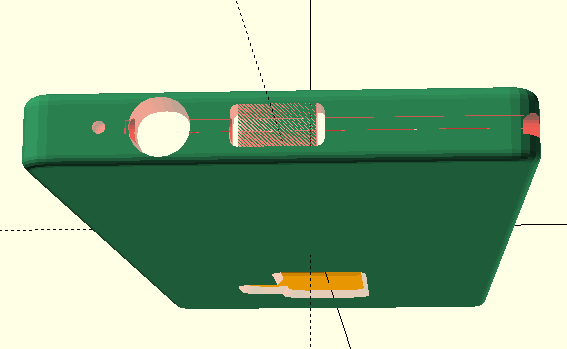
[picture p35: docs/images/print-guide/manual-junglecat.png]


Joycon rail support
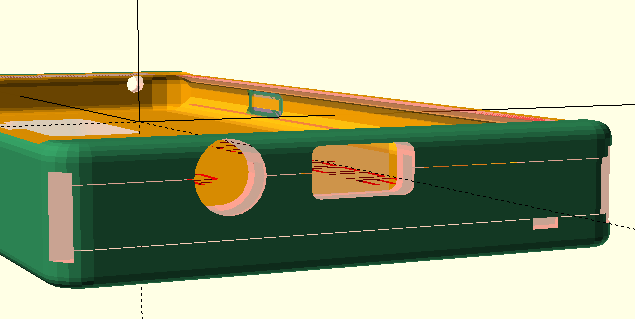
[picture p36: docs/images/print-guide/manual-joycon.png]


You must cut the Junglecat and Joycon rails by hand. Good luck! Try printing the vertical versions with no cutting.

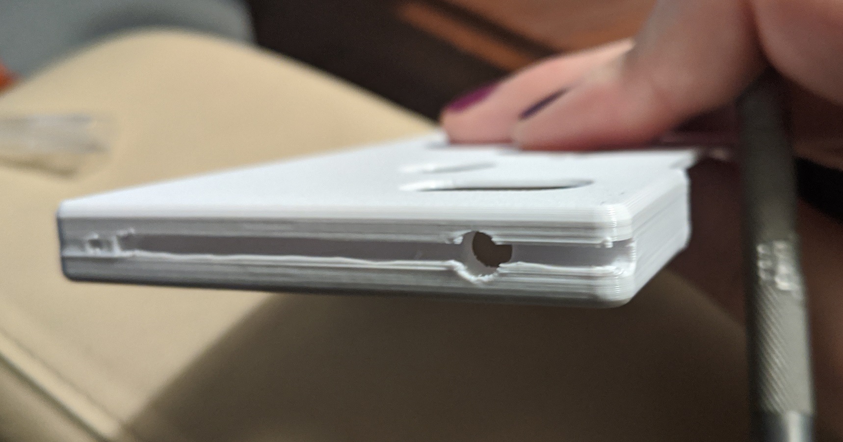
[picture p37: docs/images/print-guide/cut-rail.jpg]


...

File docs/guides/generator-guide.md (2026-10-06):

---
layout: default
title: "Phone Case Customizer"
description: "Generate custom 3D printable phone cases with OpenSCAD. Install Cuttlephone, set phone dimensions, cut out holes, and add features like gamepad rails."
permalink: /guides/generator-guide/
parent: Guides
---

# Getting the generator

## 1\) Install [OpenSCAD version 2021.01 or greater](https://openscad.org/downloads.html). 

## 2\) Get the code

You need phone_case.scad, phone_case.json, and the BOSL2 library. If you use Git, it will include the libraries.

### Clone with Git command line

Assuming you have the git command line installed:

`git clone https://github.com/SiloCityLabs/Cuttlephone.git --recurse-submodules`

Done

### Download with Github Desktop:
<!-- There must be a way for users to download without command line. Maybe I should use releases ... -->

Use GitHub Desktop to automatically include the libraries.

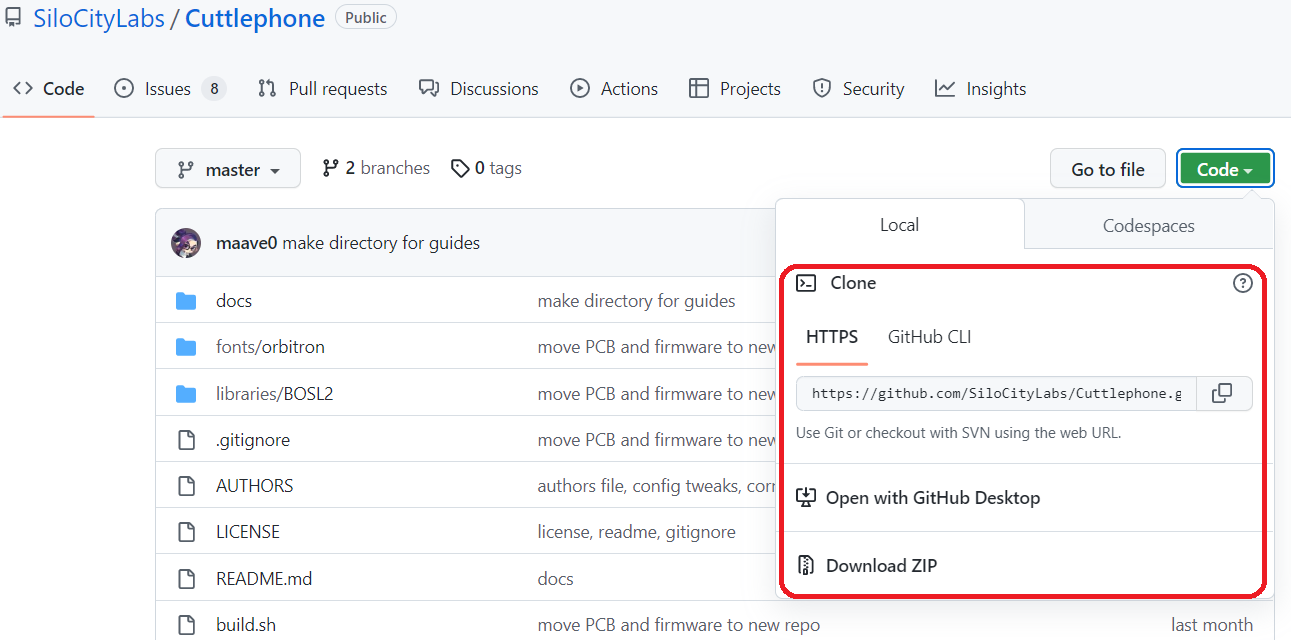
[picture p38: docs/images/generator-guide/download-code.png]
Download code (https://github.com/SiloCityLabs/Cuttlephone)


### Download ZIP

If you choose to download as a ZIP, you will also need BOSL2. Download [BOSL2 from GitHub](https://github.com/BelfrySCAD/BOSL2) and unzip to `Cuttlephone/libraries/BOSL2/`. It should look like this:

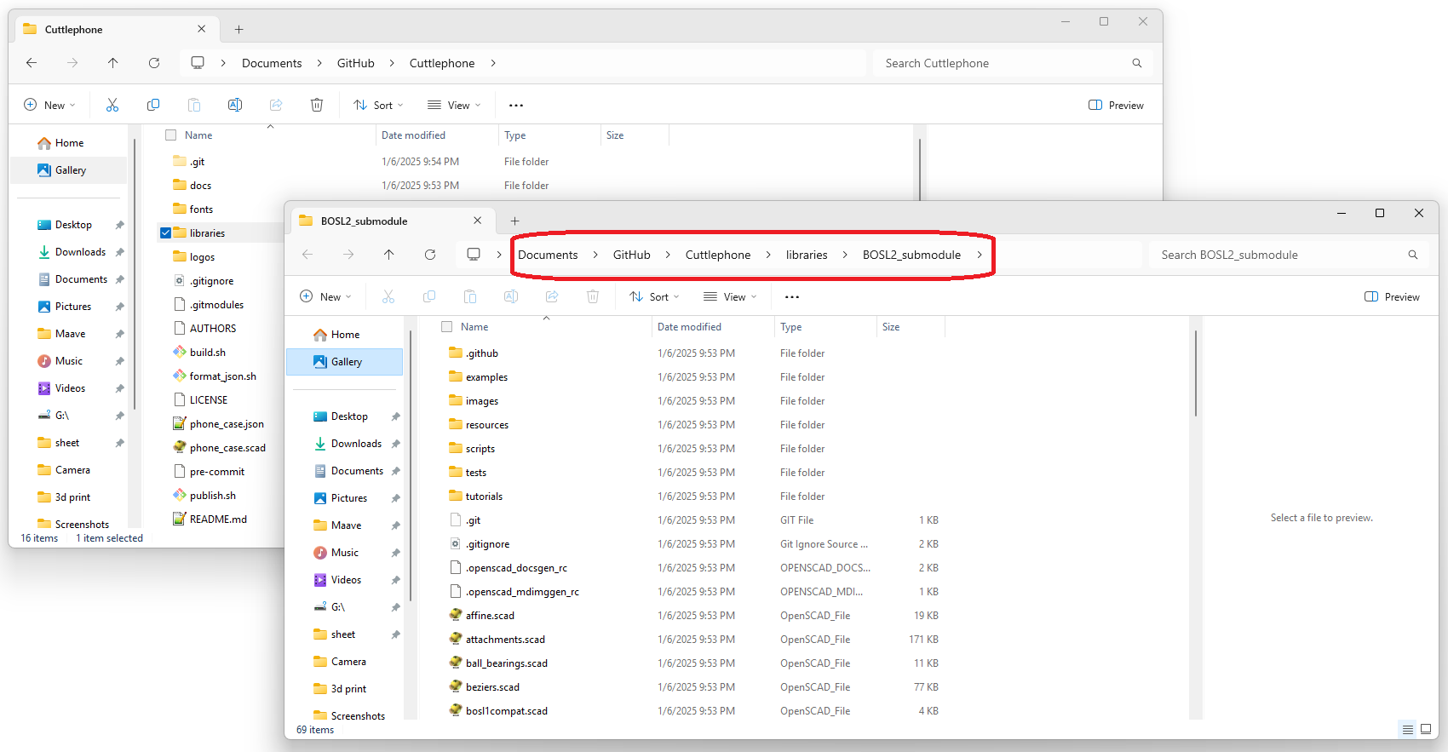
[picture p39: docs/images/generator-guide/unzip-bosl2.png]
folder structure


## 3\) Open `phone_case.scad`

Open `phone_case.scad`

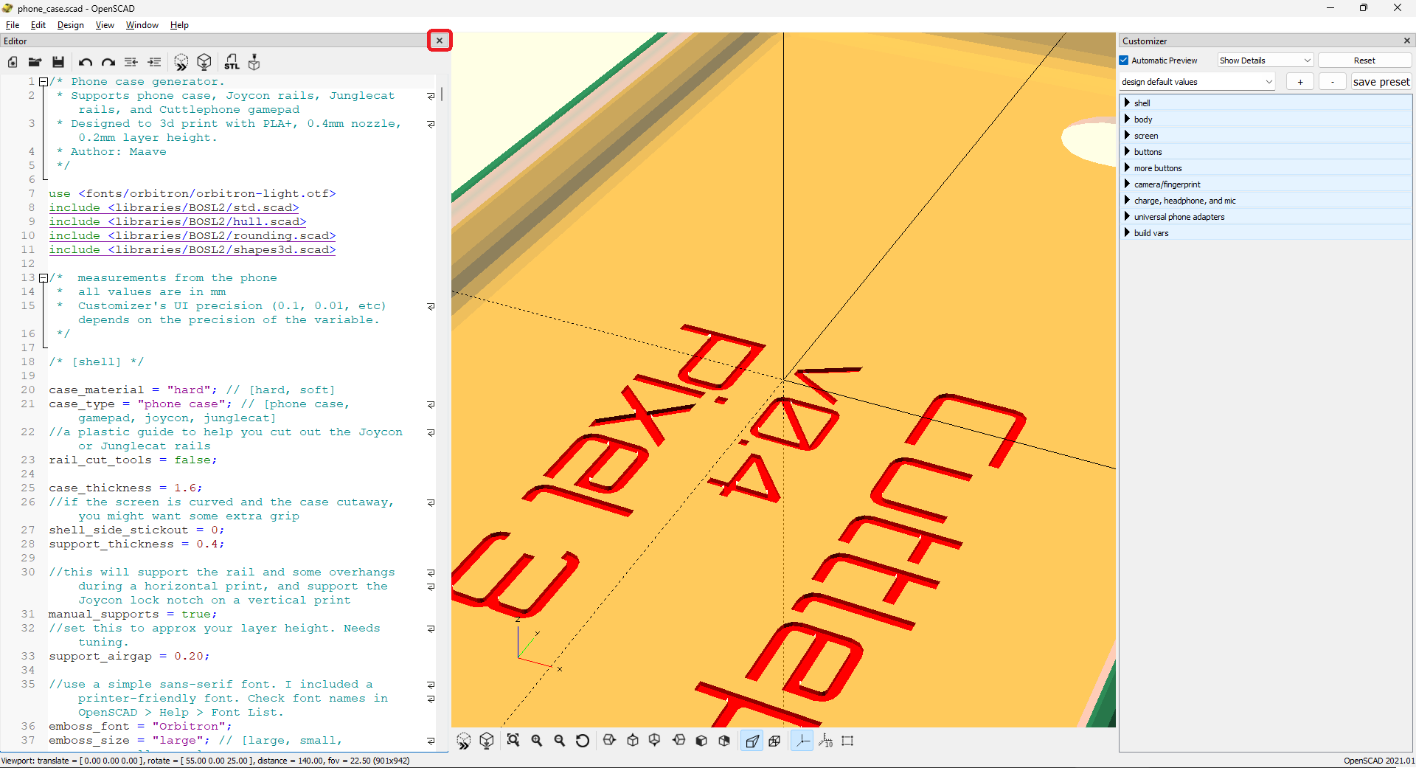
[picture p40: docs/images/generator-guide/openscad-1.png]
OpenSCAD running phone_case.scad


### Close the code editor on the left. 

### Move your phone case into view:

 - Left mouse: rotate object
 - Right mouse: pan camera
 - Scroll wheel: zoom

### Customize

Look at the Customizer on the right side. Click the section title to expand and reveal variables. The preview area will update each time you make a change. 

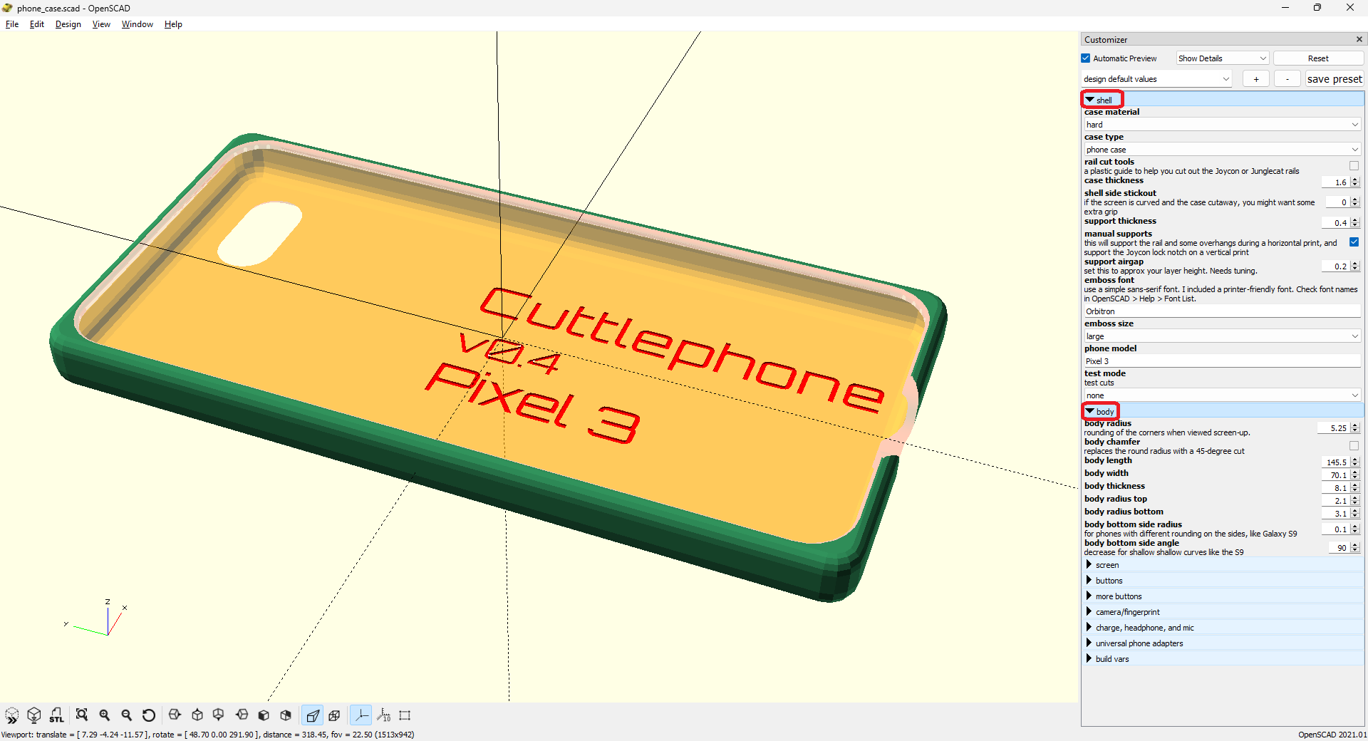
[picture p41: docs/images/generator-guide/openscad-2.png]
right side with customization values


### Try it yourself

In the "shell" section you can change the type of phone case. 

Try changing the "case type" to Junglecat - rails will get added to the side of the case. Then increase "case thickness" to 2.2 - the case becomes too thick to fit the controllers and so Junglecat wings are added.

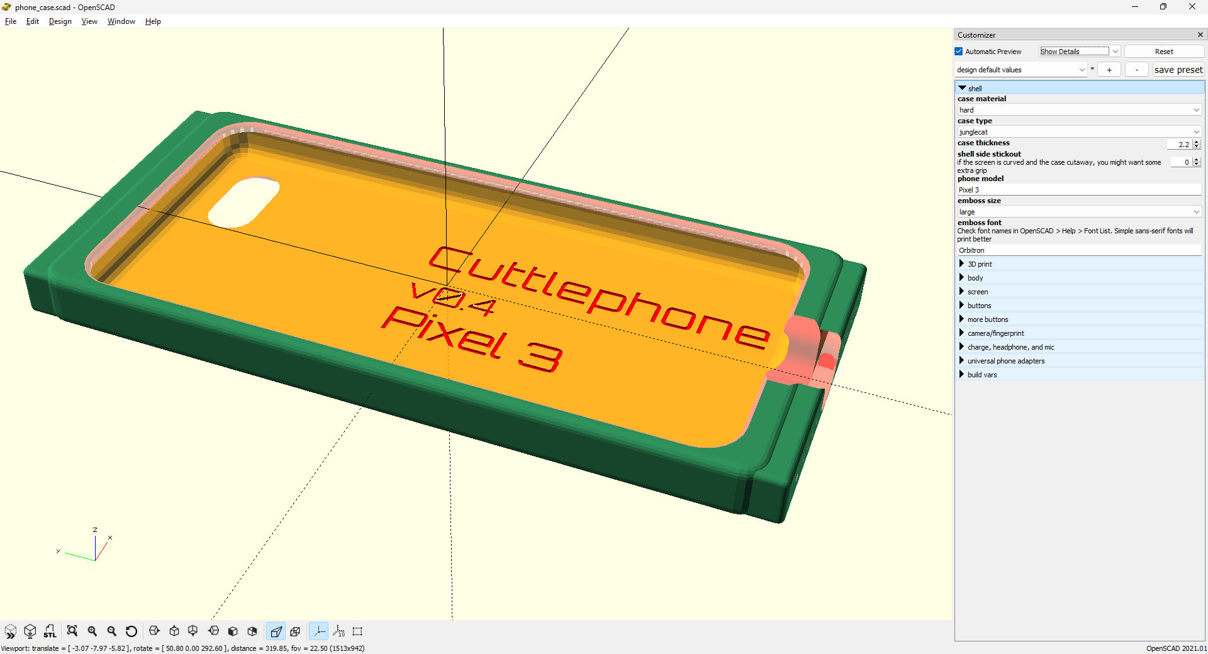
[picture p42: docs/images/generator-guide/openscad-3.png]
changing settings in the customizer


In the other sections you can change the size and features of the case. All the measurements are in millimeters. Measure your phone with calipers.

### Presets

Custom presets are saved to `phone_case.json`. Click the dropdown to view available configurations. Select one as a base config, then click the plus button **+** to make a new config.

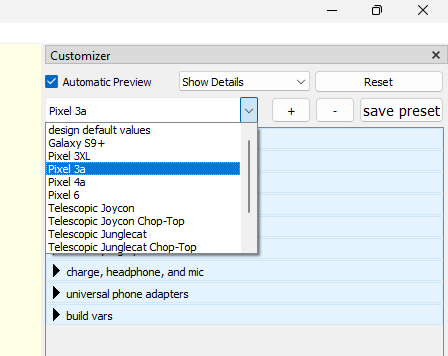
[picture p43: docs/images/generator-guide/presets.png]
OpenSCAD preset drop-down with more phone models


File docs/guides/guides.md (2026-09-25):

---
layout: default
title: Guides
description: "Guides for 3D printing phone cases and using the OpenSCAD customizer to generate your own models."
permalink: /guides/
has_children: true
---

# Guides

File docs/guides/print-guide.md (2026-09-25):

---
layout: default
title: "3D Printing"
description: "Print Cuttlephone phone cases in PLA+, PETG, ABS, or TPU. Slicer settings, supports, and tips for Joy-Con and Junglecat rails."
permalink: /guides/print-guide/
parent: Guides

---

# 3D printing guide

## Materials

The hard cases can be made using ductile materials like:
 - PLA+
 - PETG
 - ABS/ASA
 - Nylon (probably)
 
Plain PLA is too brittle and it will crack. Any brand of PLA+ (PLA Pro) will work, like Polymaker or eSun or whatever.

The soft cases can be made from TPU with a hardness of 90A or more. Overture High Speed TPU is the perfect stiffness for a phone case. I print on a Prusa i3 which is direct drive and good for printing flexibles, but this "high speed" TPU also works in bowden printers like the Ender 3. 

Dehydrating filament improves print quality for all types of filament.

## Slicer settings and tuning

Print quality is essential for Joy-Con and Junglecat rails. Tune the **linear advance setting** to prevent blobbing on the thin edge of the rails. Tune the overhangs to prevent sagging inside the rails.

I use a 0.4mm nozzle. For a quick test fit, set the layer heigh to 0.20-0.30mm. For a quality finish, set the layer height to 0.10mm-0.15mm or try variable layer thickness. Use at least 3 perimeters so that the case walls are solid.

**Variable extrusion width** will make the rails stronger and more accurate. Cura 5.0 and PrusaSlicer 2.5 both have this feature. Some companies reskin Cura as their own slicer - use the latest version of regular Cura instead.

Prusa 2.5.0 with thick rails printed as a single extrusion

Increasing the extrusion width a little may help print the thin rails in fewer stronger lines. Maybe. May reduce visual quality.

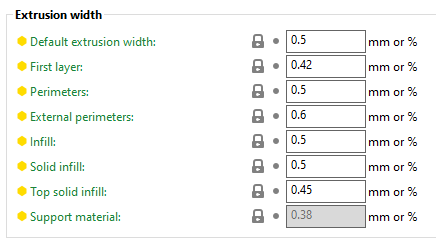
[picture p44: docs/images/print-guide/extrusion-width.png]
extrusion width setting in PrusaSlicer


To reduce blobs on TPU cases, I enable "Avoid Crossing Perimeters" in PrusaSlicer.

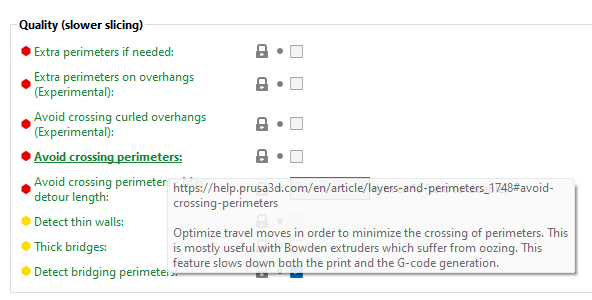
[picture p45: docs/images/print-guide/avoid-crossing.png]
Avoid Crossing Perimeters settings in PrusaSlicer


If you can print a pretty Benchy then you can print this phone case. This example is more than good enough - the corners are sharp and the overhangs barely droop.

a crispy benchy

## Separate clamps before printing - Junglecat

The clamps are made of two parts. They must be separated before printing.

Import the model into your slicer. Split the model and then move one of them. Then enable supports on the build plate only - don't fill the telescoping slot with supports.

separating the left half and right half in PrusaSlicer 1
separating the left half and right half in PrusaSlicer 2
separating the left half and right half in PrusaSlicer 3

## Separate clamps before printing - Joycon

The Joy-Con rails have manual supports for the locking notch. In your slicer there should be 4 objects. Multi-select (Ctrl+Click) and move the supports in unison with the clamp. Then enable supports on the build plate only - don't fill the telescoping slot.

separating the left half and right half, including manual supports on joycon rail

## Manual horizontal supports 

Manual supports are used for some overhangs to prevent sagging. Cut away with a craft knife or sharp box cutter. Theses are shown as thin translucent walls in OpenSCAD:

Phone overhang support

orthographic view of phone case

manual support on the USB port and speaker ports

Junglecat rail support

manual support on the junglecat rail

Joycon rail support

manual support on the joycon rail

There is a "support airgap" to help separate these rail supports ... but it only works well on the top line. You must cut the Junglecat and Joycon rails by hand. Good luck!

manual support cut away with an exacto blade

...

### Rail cut tool

Actually there is a tool to help cut the support. This guide slides into the Junglecat rail and has a channel for your blade. You need to print one for each side. 

{: .warning }
This is a work-in-progress. It's rather dangerous to cut this rail while holding the phone case. The tool grip isn't a useful shape. This needs a remake to protect the hand and sit flush on a table.

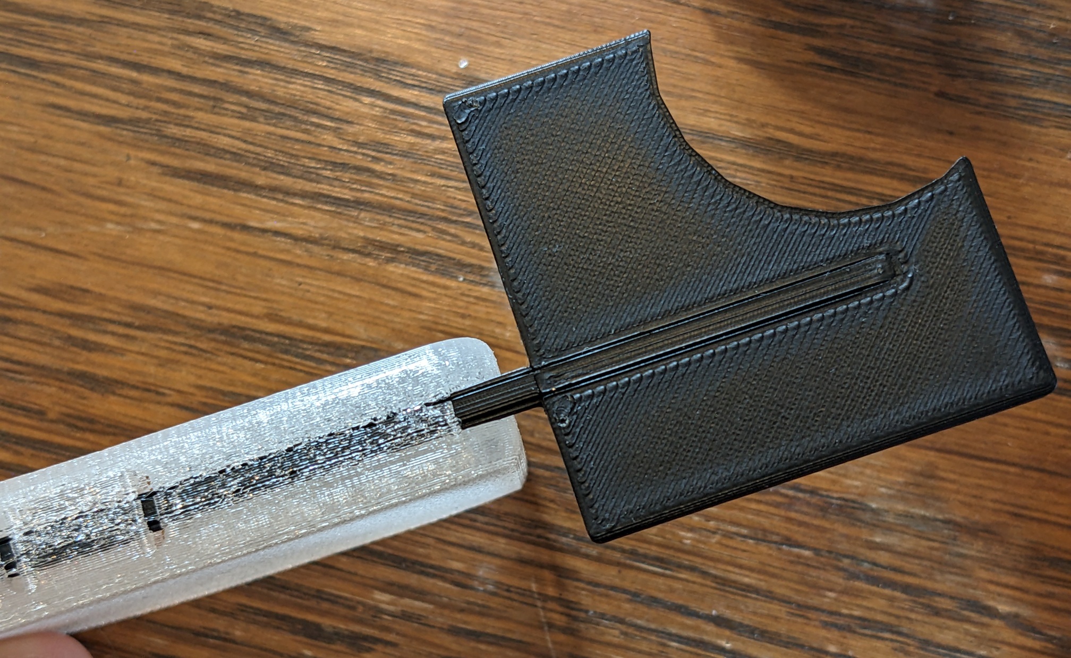
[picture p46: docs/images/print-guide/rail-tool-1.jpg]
cutting guide inserted into rail


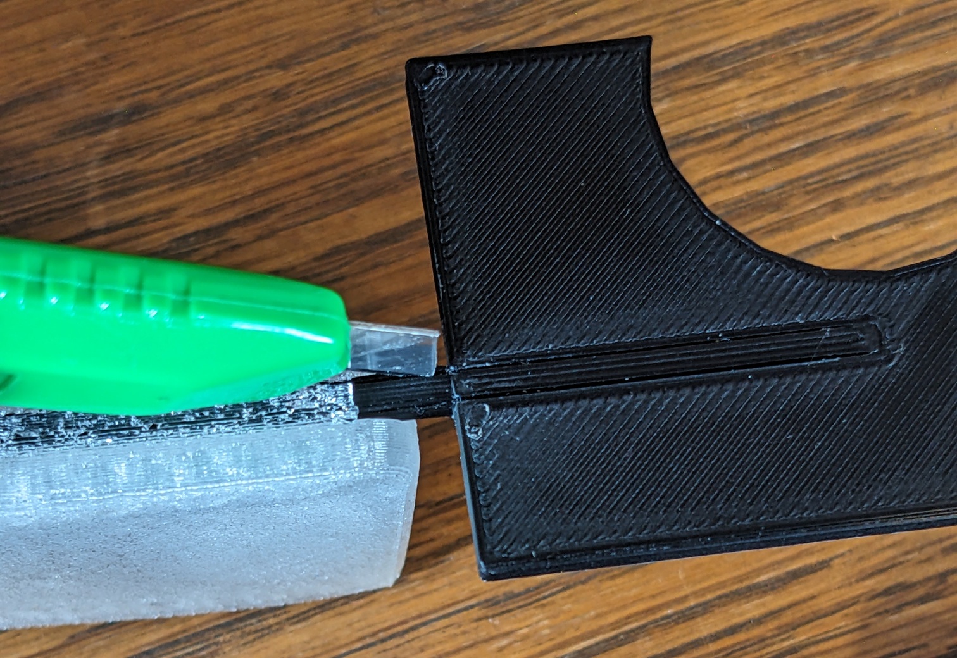
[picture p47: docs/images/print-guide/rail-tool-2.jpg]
cutting the supports with a snap-off razor


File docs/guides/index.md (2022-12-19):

# Guides

---

## [3D printing guide](print-guide/)

---

## [Phone case customizer](generator-guide/)

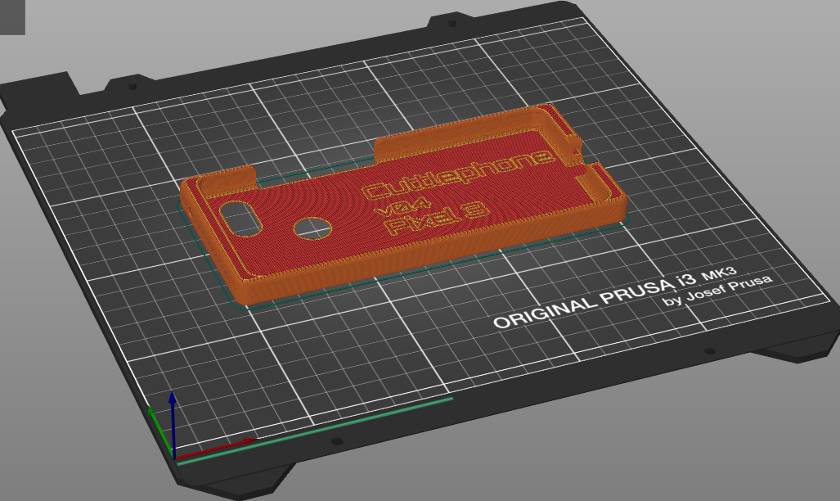
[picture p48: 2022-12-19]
docs/images/guides/print-guide.png

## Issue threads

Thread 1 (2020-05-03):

OpenSCAD mangles JSON git history

maave0, 2020-05-03:
Editing phone case configs in OpenSCAD sometimes re-arranges the JSON. This shows up in the git history and makes it harder to track real changes. Can this be fixed while still using the customizer? I didn't want to manage the JSON by hand.

ldrrp, 2020-05-14:
we could just run it through some kind of json pretty / alphebatizer site evry time we make edits idk

maave0, 2021-04-02:
I added a pre-commit sort script with commit 858222a. Unfortunately you have to copy it into .git/hooks/ yourself, but I guess that's good so people can't put arbitrary code / trojans in pre-commit bash scripts :P

I'm going to leave this issue open until it's fixed in OpenSCAD or I move off OpenSCAD. Should be easy  to sort in any language, just need to talk to devs and submit a PR.

maave0, 2022-12-12:
I suggested the change: https://github.com/openscad/openscad/issues/4447

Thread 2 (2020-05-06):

Docs in repo

maave0, 2020-05-06:
Disable wiki
Start ./docs in repo
Set GitHub pages to use ./docs

Start a case config / measuring guide

maave0, 2021-12-09:
a changed the docs to use ./docs
just need a measuring guide now

maave0, 2022-10-03:
added a print guide, that's all I got for now, other guides coming soon. You reading this, make a bug and request something

Closed 2022-10-03.

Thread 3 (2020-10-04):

port case to CadQuery

maave0, 2020-10-04:
I'm tired of OpenSCAD. It works but it's annoying. Port the case to CadQuery.

https://www.youtube.com/watch?v=lxhBNOE7GVs&feature=youtu.be
https://github.com/CadQuery/cadquery
https://docs.conda.io/en/latest/miniconda.html

I'm having environmental issues with miniconda. I'll come back to this.

maave0, 2021-09-29:
Miniconda is working now and I can install CadQuery. I'll give it a test run soon.

maave0, 2021-11-14:
testing CascadeStudio. The definable UIs look good. I don't see support for multiple parameter sets. I see the variables in the JSON - it would be possible to patch in.

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

maave0, 2021-11-14:
CadHub is cool an supports a couple different languages including OpenSCAD. Only supports 1 set of parameters [for the moment](https://github.com/Irev-Dev/cadhub/discussions/464). Needs BOSL2 support, maybe multiple-file support for fonts. It supports libraries - RoundAnything can be imported, so I could prob ask for BOSL2

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

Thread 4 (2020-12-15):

Peel-away rail supports

maave0, 2020-12-15:
Joycon and Junglecat rails need support for printing. I have a manual support option inspired by [Tokytome's Joycon knuckle dusters](https://www.thingiverse.com/thing:2337833) which leaves a slight gap between layers. It sorta works but I often can't see the line (I pull off some rail), and the technique depends on layer height (causes problems for adaptive). Removal is best done with an exacto, in which case you don't need a gap, but I'd rather it be tool-free. Make a tab that sticks out and can peel away.

maave0, 2021-09-29:
the support gap is still better than no support gap. I tried without any gap and had difficulty cutting a straight line with the exacto.

maave0, 2022-09-15:
New idea: make a completely new object to support the upper rail. I make a custom support for the Joycon lock notch (when printed vertically) and it's great

maave0, 2025-01-11:
for Junglecat I've made this rail cut guide. Work in progress

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

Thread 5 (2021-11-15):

soft buttons instead of cutout

maave0, 2021-11-15:
The soft TPU case uses cutouts for the buttons. It's ok, it's usable, but it's not as easy to hit as extended buttons, and not as easy as the full cutout like the hard cast. Add some extended buttons. This will also benefit the hybrid case

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

maave0, 2021-12-14:
started with https://github.com/SiloCityLabs/Cuttlephone/commit/f647ef8562d48892a4d82e68f6f468ca106f121b and finished with https://github.com/SiloCityLabs/Cuttlephone/commit/a3e7888014d6f1da41daac3c4c3c036c6c48a4a3

Good enough!

Closed 2021-12-14.

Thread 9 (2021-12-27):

Gamepad triggers

maave0, 2021-12-27:
The USB gamepad mode needs (preferably analog) triggers

The 8bitdo NS30 has some simple-ish tilt triggers (I think there are multiple versions of this)
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

I found some cool 3d models for the 8bitdo NS30 Pro+ (what a long name)
https://www.myminifactory.com/object/3d-print-8bitdo-sn30-pro-replacement-triggers-175984

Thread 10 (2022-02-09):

charging pass through

maave0, 2022-02-09:
I'm going to copy a lot from [PD Buddy Sink](https://git.clarahobbs.com/pd-buddy/pd-buddy-sink) and any PD projects I can get my hands on. The firmware uses ChibiOS so I'll have to convert.

The USB PD is usually handled by a dedicated chip via I2C. I'd need 2 - one to negotiate with phone, the other to negotiate with charger. Or one that handles multiple.
Doing it on the STM32 may complicate code. Some STM32 chips have a PD ability like STM32L5, STM32G0, STM32G4

FUSB302BMPX
https://www.onsemi.com/products/interfaces/usb-type-c/fusb302b
Used by PD Buddy Sink and [OtterPill breakout board](https://github.com/Jana-Marie/OtterPill/)

STUSB4500
with stm32 example (not using chibi os)
https://github.com/usb-c/STUSB4500
can be programmed standalone without a micro
https://hackaday.com/2019/10/18/usb-power-delivery-for-all-the-things/

EJ899
used on no-name usb hub

voltage regulator for chip/logic
I could just stick with 5V (for easy data lines) and support 5v 3a fast charging
PD Buddy Sink uses AP2204R-3.3TRG1 for 3.3v, and I think the FUSB302 can negotiate 3.3v data
OtterPill has a SY8201 to provide 3.3v

maave0, 2022-12-12:
repo has been moved: https://github.com/SiloCityLabs/Cuttlephone-Gamepad/issues/1

Closed 2022-12-12.

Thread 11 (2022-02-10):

USB hub support

maave0, 2022-02-10:
for this part I'll be ripping off USB hubs. ldrrp gave me a hub to disassemble

USB data hub/mux chip
found on no-name chinese hubs. Chip can be found on aliexpress
GL3510

maave0, 2022-12-19:
moved repos for PCB
https://github.com/SiloCityLabs/Cuttlephone-Gamepad/issues/2

Closed 2022-12-19.

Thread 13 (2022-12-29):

image imprint on case

maave0, 2022-12-29:
It's logo time. Maybe we can let users import their own image.

Image to OpenSCAD options:

https://en.wikibooks.org/wiki/OpenSCAD_User_Manual/Other_Language_Features#surface

latest version has PNG import. Screw the other options

...

use inkscape to generate OpenSCAD path code. It would be imported in `phone_case.scad` similar to the libraries:

https://www.instructables.com/Convert-any-2D-image-to-a-3D-object-using-OpenSCAD/

start with a PNG image. Change to greyscale. Use Imagemagick to output a raw binary format, then Ruby code to write a .dat file. Use openscad surface:

https://cubehero.com/2013/11/25/emboss-and-impress-images-onto-a-surface-in-openscad/

maave0, 2023-01-13:
surface() performance is poor. It creates a bunch of triangles. [Forums recommend 100x100 pixels max](https://forum.openscad.org/Surface-from-PNG-and-difference-td12517.html). I can handle a 275x275 px PNG on my laptop but it looks chunky when imported:

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

maave0, 2023-01-14:
OpenSCAD import() looks great and perform well. DPI setting has no noticeable effect. I used Inkscape to convert the traced PNG to SVG.

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

maave0, 2023-01-14:
better PNG import is coming later: https://github.com/openscad/openscad/pull/1110

SVG will do for now

Closed 2023-01-14.

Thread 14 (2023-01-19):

embossed text font

maave0, 2023-01-19:
The Splatfest art design clashes with the current digital text. Can we get a softer sans-serif font? Fonts must be licensed with a permissive open source license or free-use license. OFL is good.

display font:

`A display typeface is a typeface that is intended for use at large sizes for headings, rather than for extended passages of body text.`

Some are nice, some are too flashy.

relief font:

`Relief SingleLine is a versatile sans serif “single-line” font with open paths oriented towards CNC (Computer Numerical Control) and fab labs environments.`

Not sure if needed. This is additive manufacturing, I'm not cutting a line. I need to be able to control the line width in Cuttlephone for this to work. Or pre-bolden the text.

maave0, 2023-01-19:
[Orbitron](https://fonts.google.com/specimen/Orbitron)
nice visibility. It doesn't feel like a perfect match but feels better than most

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

[Relief SingleLine Outline](https://github.com/isdat-type/Relief-SingleLine)
even if it was bold, I'm not feeling it

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

[Roboto](https://fonts.google.com/specimen/Roboto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)
not quite right

[Ubuntu](https://fonts.google.com/specimen/Ubuntu?category=Sans+Serif,Display,Handwriting,Monospace&preview.text=Cuttlephone%20Pixel%20Samsung%201234567890&preview.text_type=custom)

maave0, 2023-01-21:
The dude logo came out excellent. The text came out decent. "Cuttlephone" is good at big scale. The small scale text is too small. "4" and "a" especially are not readable; the little blob islands don't look good.

I should try ironing in the slicer

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

maave0, 2023-01-22:
Getting sidetracked ... These are not suitable for selling mainstream but they are FUN. Some look like they'll be legible in a 3D print. I'll make some test prints with these fonts and try them out.

https://kirbypost-generator.tumblr.com/post/181817656650/octo-expansion-font-recreations-the-haikarawalker

Deepsea Block
looks printable but I don't care for the style
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

Deepsea Line
gorgeous! I can learn the letters. It's rather thin but I think it'll show in a 3D print
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

There aren't many tiny blob areas. I only see a little that I'm concerned about
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

Deepsea Stencil
very nice, bolder design, but more fine details islands that may not print
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

Splatoon2 Neon
this looks not printable, too many detail islands. This font doesn't have any extras characters like "." or "-". I'd have to make them.
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

maave0, 2025-01-11:
Audiowide is the new default. These fonts are included in the /font directory:
Audiowide
Baloo 2
Octo Expansion font recreations
orbitron

Closed 2025-01-11.

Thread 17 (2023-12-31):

Known good models vs generated models

maave0, 2023-12-31:
at some point I broke the telescopic connection. Minor breaks are getting to be an issue. I want a "known good" or "hall of fame" section of 3D models on the website. Hand picked, maybe set up for printing.
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

Additionally, we need STL as a available download. Some users can't use 3MF.

example Hall of Fame-r, Joycon vertical, with lock-notch support and moved for printing, STL format

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

[joycon vertical.zip](https://github.com/SiloCityLabs/Cuttlephone/files/13802170/joycon.vertical.zip)

maave0, 2025-01-11:
The website has been updated with a "Featured Models" page:
docs/featured-models.md

https://cuttlephone.com/models/featured-models/

maybe I'll use releases later

Closed 2025-01-11.

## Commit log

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2019-06-23 tweak pcb outline for usb connector. Update gitignore
    [avr-gamepad.kicad_pcb]
2019-07-09 pcb alignment hole, tweak CC resistor positions and start-select pads
    [avr-gamepad.kicad_pcb]
2019-07-13 replace headers with FFC connector. Adjust outline. Update gitignore
    [avr-gamepad.kicad_pcb, avr-gamepad.sch]
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2019-07-14 trying and failing to autoroute with thicker power and ground traces
    [avr-gamepad.kicad_pcb]
2019-07-16 move FFC connector and increase power and ground track width
    [avr-gamepad.kicad_pcb]
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2019-07-21 rearrange, reroute, DRC fixes
    [avr-gamepad.kicad_pcb]
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2019-09-29 begin v2. Remove flex, move components to one side, expand board size, remove excess caps, recess usb connector
    [avr-gamepad.kicad_pcb, avr-gamepad.sch]
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2019-09-30 pin swapping and component shuffling
    [avr-gamepad.kicad_pcb, avr-gamepad.sch]
2019-10-01 move footprints to new dir, increase contact size, add squidward
    [avr-gamepad.kicad_pcb, avr-gamepad.sch]
2019-10-02 kill the double sided feature, make it 2 boards, import mousebites
    [avr-gamepad.kicad_pcb, avr-gamepad.sch]
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2019-10-04 add 0.1 in headers, label atmega pins better
    [avr-gamepad.kicad_pcb, avr-gamepad.sch]
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2020-01-02 move PCB files to a sub directory. Create sub directory for case 3d model
    [avr-gamepad.csv, avr-gamepad.kicad_pcb, avr-gamepad.sch]
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2020-01-04 separate body radius from body thickness. Start joycon rail shell
    [phone_case.scad]
2020-01-04 convert line endings to unix, ruining the git history
    [phone_case.scad]
2020-01-05 add manual support for joycon rail, cut joycon lock notch
    [phone_case.scad]
2020-01-10 begin implementing junglecat rails, fix joycon shell thickness, tweak mic cut for joycon rail
    [phone_case.scad]
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2020-01-11 fix? gamepad button offset, reduce default airgap
    [phone_case.scad]
2020-01-14 tweak gamepad shell triggers, button holes, and faceplate pegs. 45 degree cut PCB corners. test add ffc connector for joystick
    [avr-gamepad.kicad_pcb, avr-gamepad.sch, phone_case.scad]
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2020-01-30 readme pic, change screen length to screen lip in customizer
    [phone_case.scad]
2020-02-10 make it easier to remove joycon rail support. STL build script. Emboss version info in case
    [phone_case.scad]
2020-02-14 use json configs in build script, hide junglecat rails until they work
    [phone_case.scad]
2020-04-06 move configs to single file (the way it should be). Add Pixel 3a support
    [phone_case.scad]
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2020-04-12 extra screen lip, rounded cut corners to prevent snagging, galaxy s9+ support
    [phone_case.scad]
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2020-04-13 change left/right on schematic, start arranging pcb, add pcf8574 footprint
    [avr-gamepad.kicad_pcb, avr-gamepad.sch]
2020-04-13 disabled extra buttons, fixed R-L conversion
    [avr-gamepad.kicad_pcb, avr-gamepad.sch]
2020-04-13 swap left/right board sides for fab assembly
    [avr-gamepad.kicad_pcb, avr-gamepad.sch]
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2020-04-14 pcb rearranging, placeholder footprint for right angle tact switches
    [avr-gamepad.kicad_pcb, avr-gamepad.sch]
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2020-04-16 make lib paths relative, add footprints to mcp23008 breakout, chuck into pcbnew
    [MCP23008.kicad_pcb, MCP23008.sch]
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2020-05-03 authors file, config tweaks, corner cut for headphone jack
    [phone_case.scad]
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2020-05-09 s9 tweaks, fix var named the same as a function
    [phone_case.scad]
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2020-08-12 build STL cus 3mf rendered weird, fix variable name conflict
    [phone_case.scad]
2020-08-27 make screen lip less sharp. Add lanyard slot. Fix pixel 3a scren radius
    [phone_case.scad]
2020-08-27 change mic hole for stiffness. Change bottom speaker cutout for stiffness
    [phone_case.scad]
2020-09-05 consolidate left/right button cuts. Replace Project Paintball with a commercial compatible font
    [phone_case.scad]
2020-09-19 fix geometry calculations with BOSL shapes, add 1x04 FFC, experimental trigger
    [avr-gamepad.kicad_pcb, phone_case.scad]
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2021-04-01 build all versions of case in build script
    [phone_case.scad]
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2021-04-02 improve case_type_override, fix/move pre-commit
    [phone_case.scad]
2021-04-09 round inside edge, add independent screen corner rounding for better grip
    [phone_case.scad]
2021-10-31 fix build script importing text. Start osft TPU case
    [phone_case.scad]
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2021-11-07 add support for TPU overhangs. Add side edge debug cut
    [phone_case.scad]
2021-11-07 rearrange customizer variables, add customizer tabs, tweak Fn
    [phone_case.scad]
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2021-12-12 fix a bunch of soft button logic
    [phone_case.scad]
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2021-12-15 Increment version to 0.2. Update code for BOSL2. Round the edges of the junglecat/joycon rail cases more
    [phone_case.scad]
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2021-12-30 allow bottom mic cut, fix newlines and tabs
    [phone_case.scad]
2022-01-02 fix soft button alignment
    [phone_case.scad]
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2022-03-08 playing with Galaxy S9 curves, tweak USB port cut
    [phone_case.scad]
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2022-03-11 fix joycon screen cut
    [phone_case.scad]
2022-04-05 re-learn trig to make a fillet function for S9 case
    [phone_case.scad]
2022-04-08 fix extra_lip
    [phone_case.scad]
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2022-04-24 fix the sharp corner on the Galaxy S9+ curved back
    [phone_case.scad]
2022-04-29 fix build script and bug-workaround variables
    [phone_case.scad]
2022-04-29 update version to 0.3 because the S9+ works!
    [phone_case.scad]
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2022-06-19 make a separate publish script. Publish universal grips
    [Galaxy S9+ joycon hard.3mf, Galaxy S9+ joycon soft.3mf, Galaxy S9+ junglecat hard.3mf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]
2022-06-19 rotate option for cases that should be printed vertically
    [phone_case.scad]
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2022-07-10 publish two-piece fix
    [Galaxy S9+ joycon hard.3mf, Galaxy S9+ joycon soft.3mf, Galaxy S9+ junglecat hard.3mf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]
2022-07-10 allow mic cuts on both top and bottom. Put format_json.sh back so I use it more
    [phone_case.scad]
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2022-07-14 allow supports for the soft button cutouts. Xperia 1 III tweaks
    [phone_case.scad]
2022-07-16 galaxy S9+ tweaks, screen recess, button tweaks, cleanup
    [phone_case.scad]
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2022-10-03 updating build scripts and which cases are displayed on the site
    [phone_case.scad]
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2022-10-17 build fixed support tower
    [Galaxy S9+ joycon hard.3mf, Galaxy S9+ joycon soft.3mf, Galaxy S9+ junglecat hard.3mf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]
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2023-04-01 tweak joycon fit, add joycon tablet edition, generic speaker holes for telescopic, pocket for telescopic mode. Add Sia logos
    [phone_case.scad]
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2023-07-05 Soft case: Added toggles for the serrated power button texture, exposed button protrusion in customizer
    [phone_case.scad]
2023-07-05 $fn now defaults to highFn, replaced arbitrary $fn values by either the lowFn or the highFn variables
    [phone_case.scad]
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2023-07-05 Customizer: added several step size values per OpenSCAD user manual
    [phone_case.scad]
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2023-07-05 soft_cut(): added usb_cut_height, split horizontal and vertical clearance parameters
    [phone_case.scad]
2023-07-05 Added "combine fingerprint and camera opening" option - works particulaly well on thicker cases for something like the Pixel 5.
    [phone_case.scad]
2023-07-05 Use an expanded camera bar as part of the shell model if the bar protrudes out of the case
    [phone_case.scad]
2023-07-05 Customizer: added charge port, camera cutout, fingerprint bevel angles
    [phone_case.scad]
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2023-07-05 Bottom speaker cutouts positioning fix
    [phone_case.scad]
2023-07-05 Soft buttons rework, improved default shape, more configuration options
    [phone_case.scad]
2023-07-05 Added Bézier-surface-based bezels including adjustable shell_screen_lip_outer and _inner thicknesses in the Customizer
    [phone_case.scad]
2023-07-05 Changed default set model to "DO NOT USE"
    [phone_case.scad]
2023-07-05 phone_case.json: renamed button_recess to button_body_protrusion, corrected values
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2023-08-12 Pixel 4a tweaks, jungelcat rail rounding, printing guide
    [phone_case.scad]
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2025-01-09 tweak joycon adapter, tighten joycon rail, add speaker slots, failsafe for button_cut_rounding, add test mode for openscad viewing
    [phone_case.scad]
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2025-06-01 fix junglecat position and tweak junglecat rail thickness
    [phone_case.scad]
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2026-07-13 Allow thicker back side.
    Helps protect the camera of the ZTE Blade V70 Max better.
    [phone_case.scad]
2026-07-13 Allow a separate radius for the second camera hole.
    Necessary for the ZTE Blade V70 Max as it has a second hole for the
    camera's flash.
    [phone_case.scad]
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2026-09-15 build skip in_development
    [phone_case.scad]
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2026-10-06 swap phone case logi for sia head
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
